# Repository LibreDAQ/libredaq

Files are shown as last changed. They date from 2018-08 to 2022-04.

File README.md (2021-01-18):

# LibreDAQ official repository

LibreDAQ is a versatile, modular and hackable Data Acquisition (DAQ) platform. 
This repository includes the sources for: 
* Circuit schematics
* C++ SDK
* C++ examples
* Firmware
* ROS node
* LibreDAQStudio

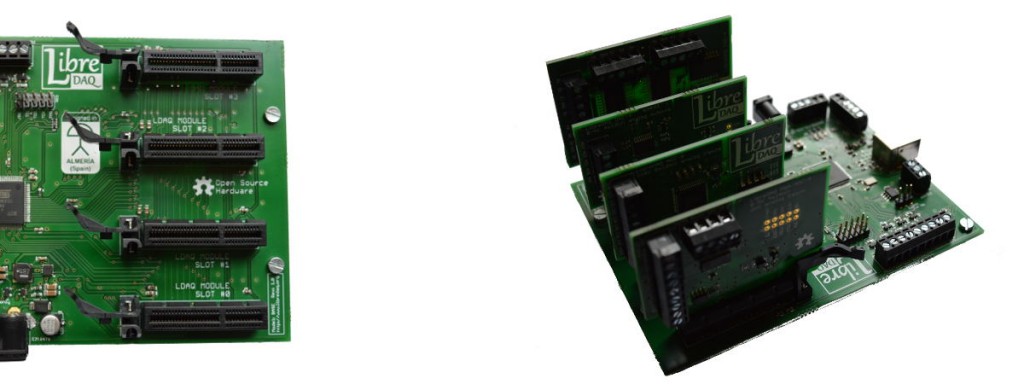
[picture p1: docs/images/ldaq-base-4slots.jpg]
LibreDAQ Picture


# Cite as: 

* Blanco-Claraco, J. L., López-Martínez, J., Torres-Moreno, J. L., & Giménez-Fernández, A. (2015). **A Low-Cost Modular Platform for Heterogeneous Data Acquisition with Accurate Interchannel Synchronization**. *Sensors*, 15(10), 27374-27392 ([PDF](https://www.mdpi.com/1424-8220/15/10/27374/pdf)).
* BibTex:
```
@article{blanco2015low,
  title={A Low-Cost Modular Platform for Heterogeneous Data Acquisition with Accurate Interchannel Synchronization},
  author={Blanco-Claraco, Jos{\'e} Luis and L{\'o}pez-Mart{\'\i}nez, Javier and Torres-Moreno, Jos{\'e} Luis and Gim{\'e}nez-Fern{\'a}ndez, Antonio},
  journal={Sensors},
  volume={15},
  number={10},
  pages={27374--27392},
  year={2015}
}
```

# CircuitHub

* [LibreDAQ Base board](https://circuithub.com/projects/LibreDAQ/ldaq-base-v11)

# Videos:

[YouTube playlist](https://www.youtube.com/playlist?list=PLOJ3GF0x2_eULIKMOQqdDnZAjOUo_N2IJ)

YouTube videos

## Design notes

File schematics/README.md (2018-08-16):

All LibreDAQ schematics are published under the following License:

[Attribution-NonCommercial-ShareAlike 4.0 International](https://creativecommons.org/licenses/by-nc-sa/4.0/)

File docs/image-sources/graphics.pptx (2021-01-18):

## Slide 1

PC

LibreDaq
Base

Module

µController

LibreDaq
Mini

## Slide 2

LDS Interface

Analog & Digital I/Os

…

USB
(480 Mbps)

…

(4 Slots)

USB
(480 Mbps)

Analog & Digital I/Os

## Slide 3

RS/EIA-485 BUS

LDS Interface

Analog & Digital I/Os

…

USB
(480 Mbps)

…

Analog & Digital I/Os

…

LDS Interface

…

Analog & Digital I/Os

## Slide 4

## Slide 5

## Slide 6

P1

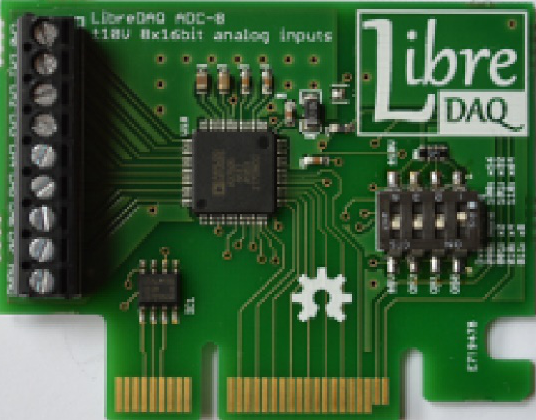
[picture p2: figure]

LDS

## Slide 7

P1

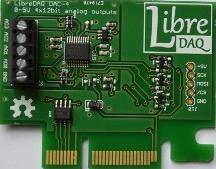
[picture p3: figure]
Screen Clipping

LDS

P2

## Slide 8

P3

P4

P2

P1

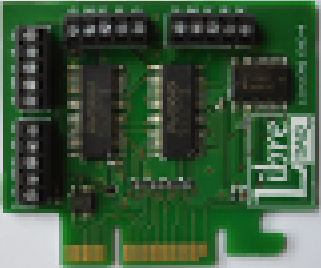
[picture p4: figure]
Screen Clipping

LDS

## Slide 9

P2

P1

P3

LDS

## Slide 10

P2

P3

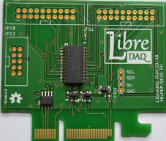
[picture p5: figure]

P1

P4

LDS

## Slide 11

P2

P1

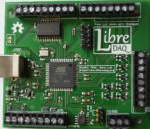
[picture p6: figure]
ldaq-mini-pic1-lowres

USB

P3

P6

P4

P5

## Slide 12

P1

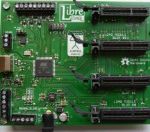
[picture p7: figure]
ldaq-base-pic1-lowres

SLOT3

USB

P2

SLOT2

P3

SLOT1

P5

SLOT0

P4

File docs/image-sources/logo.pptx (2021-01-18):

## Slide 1

L

L

L

ibre

DAQ

VOLTIO1

ibre

DAQ

MINI

ibre

DAQ

PRO

L

L

ibre

DAQ

VOLTIO2

ibre

DAQ

MUEVE

L

ibre

DAQ

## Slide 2

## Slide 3

Designed in

ALMERÍA
(Spain)

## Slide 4

L

DAQ

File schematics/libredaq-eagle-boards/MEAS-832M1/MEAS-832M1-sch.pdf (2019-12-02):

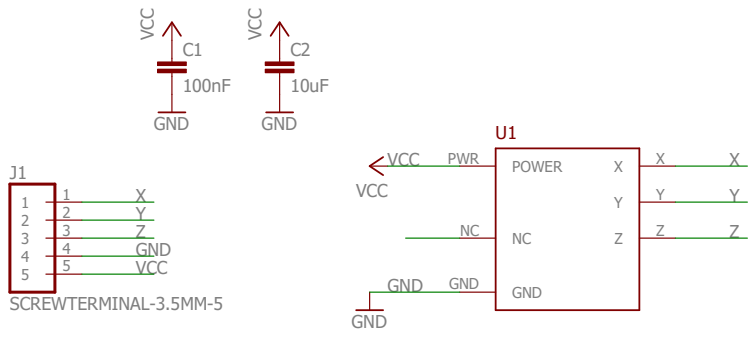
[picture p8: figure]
SCREWTERMINAL-3.5MM-5; GND; VCC VCC; VCC; POWER PWR; GND GND

29/11/2019 17:01 C:\Dropbox\Work\HW\LibreDAQ\libredaq-eagle\MEAS-832M1\MEAS-832M1.sch (Sheet: 1/1)

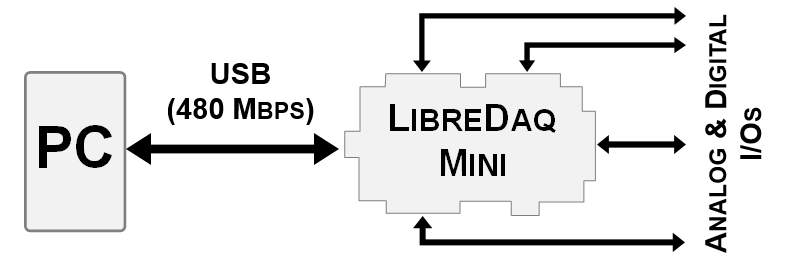
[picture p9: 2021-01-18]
docs/images/ldaq-overview2.png

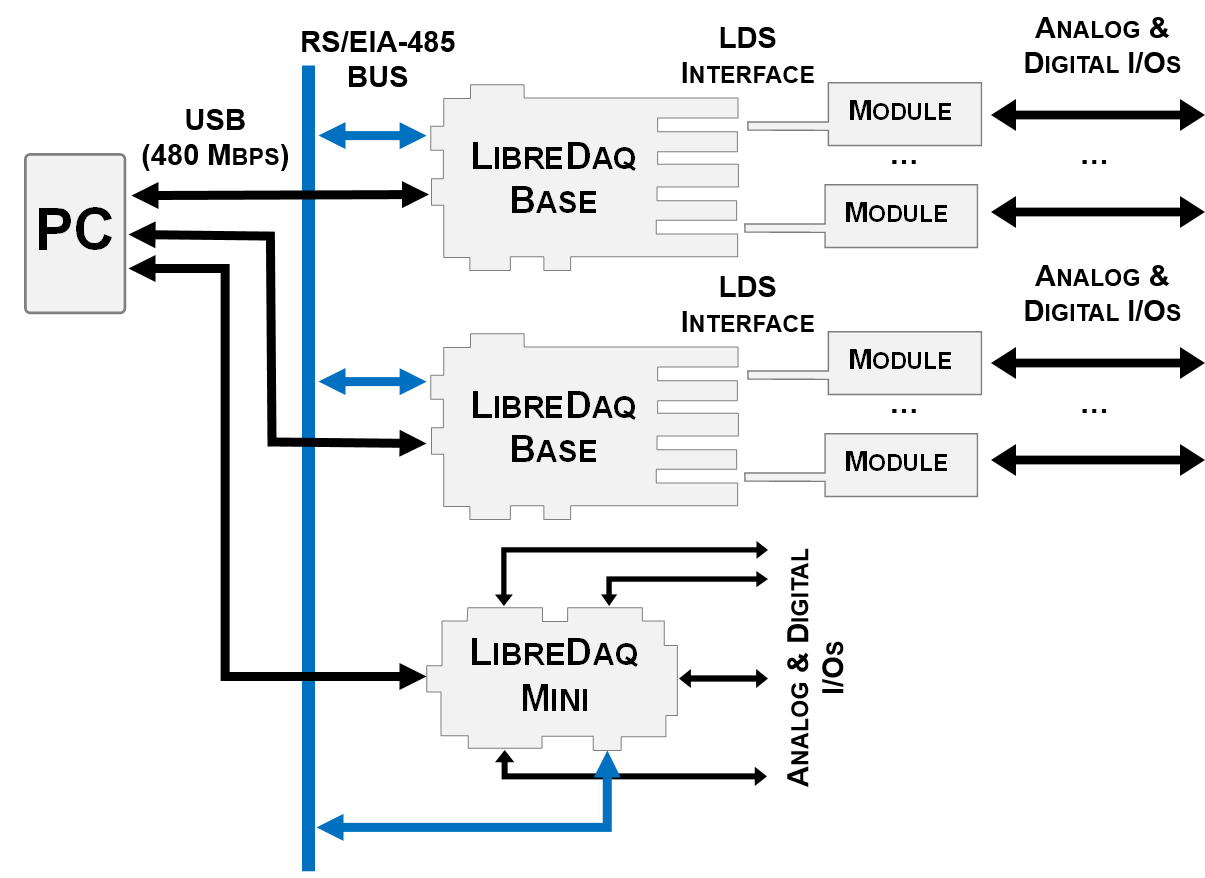
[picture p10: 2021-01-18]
docs/images/ldaq-overview3.png

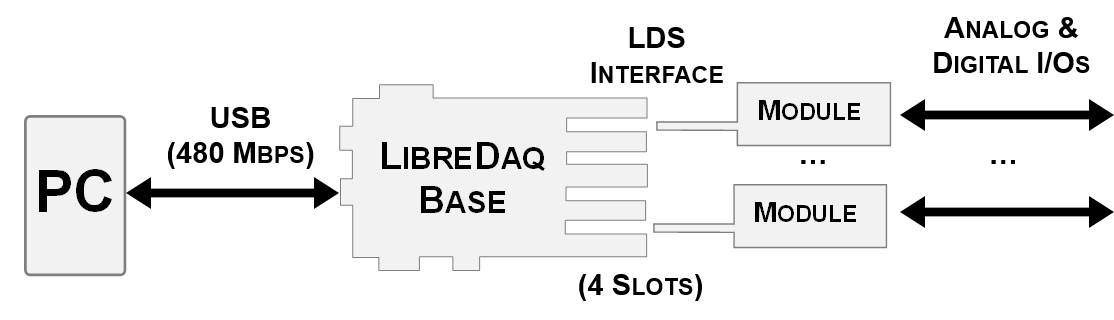
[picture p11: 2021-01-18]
docs/images/ldaq-overview1.png

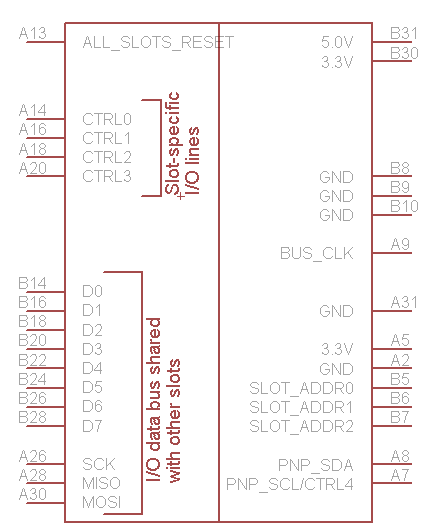
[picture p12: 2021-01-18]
docs/images/LibreDAQ_LDS_Signals.png

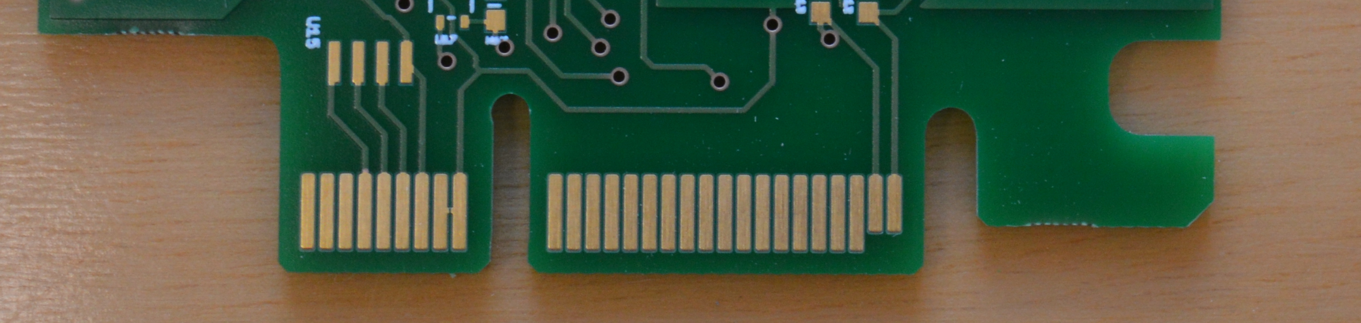
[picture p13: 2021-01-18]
docs/images/LDS-interface-front.jpg

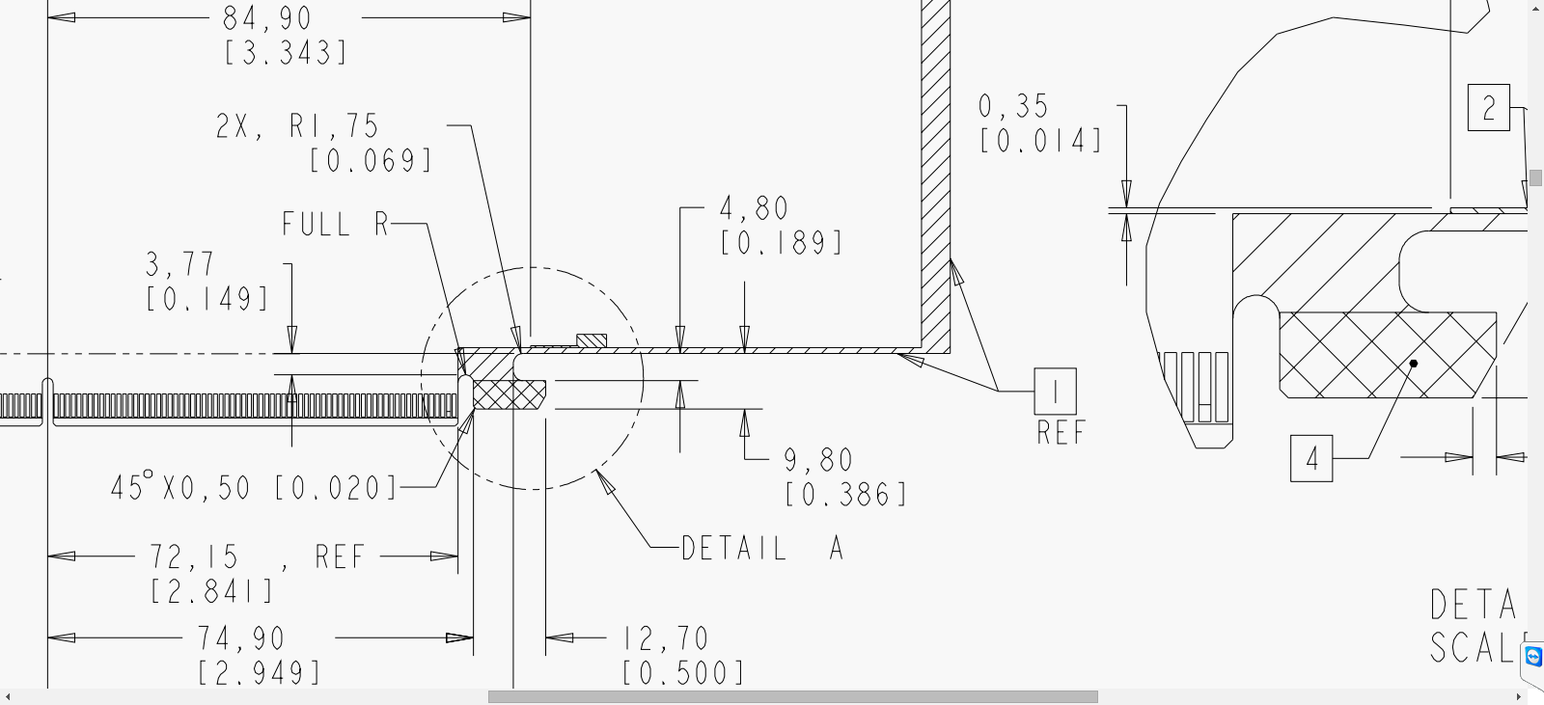
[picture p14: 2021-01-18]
docs/images/pci-express.png

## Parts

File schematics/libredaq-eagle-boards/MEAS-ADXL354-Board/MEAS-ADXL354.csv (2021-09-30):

Qty | Value | Device | Package | Parts | Description | ARROW_PART_NUMBER | ARROW_PRICE-STOCK | DESCRIPTION | HEIGHT | MANUFACTURER_NAME | MANUFACTURER_PART_NUMBER | MOUSER_PART_NUMBER | MOUSER_PRICE-STOCK
4 | 0.1uF | 8,85012E+11 | CAPC1005X55N | C2, C4, C6, C9 | Multilayer Ceramic Chip Capacitor WCAP-CSGP Series 0402 100000pF X5R0402104M010DFCT10000 |  |  | Multilayer Ceramic Chip Capacitor WCAP-CSGP Series 0402 100000pF X5R0402104M010DFCT10000 | 0.55mm | Wurth Elektronik | 8,85012E+11 | 710-885012105010 | https://www.mouser.co.uk/ProductDetail/Wurth-Elektronik/885012105010?qs=0KOYDY2FL298aE%252BL5D%252BNKw%3D%3D
4 | 1.0uF | LMK105BJ225KV-F | CAPC1005X55N | C1, C3, C5, C8 | TAIYO YUDEN - LMK105BJ225KV-F - CAP ,MLCC ,0402,10V ,X5R,2.2UF10% ,T&R |  |  | TAIYO YUDEN - LMK105BJ225KV-F - CAP ,MLCC ,0402,10V ,X5R,2.2UF10% ,T&R | 0.55mm | TAIYO YUDEN | LMK105BJ225KV-F | 963-LMK105BJ225KV-F | https://www.mouser.co.uk/ProductDetail/Taiyo-Yuden/LMK105BJ225KV-F?qs=lkMpTOwszhdMcDOeuc5Dig%3D%3D
1 | 1725698 | 1725698 | 1725698 | J2 | Conn PC Terminal Block 6 POS 2.54mm Solder ST Thru-Hole 6A |  |  | Conn PC Terminal Block 6 POS 2.54mm Solder ST Thru-Hole 6A | 8.65mm | Phoenix Contact | 1725698 | 651-1725698 | https://www.mouser.co.uk/ProductDetail/Phoenix-Contact/1725698?qs=Ul7CXFMnlWUIR3VpVwwC4A%3D%3D
1 | ADXL354CEZ-RL7 | ADXL354CEZ-RL7 | PLCC127P602X560X205-14N | IC1 | Accelerometer Triple +/-2g/+/-8g 3.3V 368mv/g to 432mv/g/92mv/g to 108mv/g 14-Pin CLLCC T/R |  |  | Accelerometer Triple +/-2g/+/-8g 3.3V 368mv/g to 432mv/g/92mv/g to 108mv/g 14-Pin CLLCC T/R | 2.05mm | Analog Devices | ADXL354CEZ-RL7 |  | https://www.digikey.com/es/products/detail/analog-devices-inc/ADXL354CEZ-RL7/6618309
1 | SFR03EZPF6801 | SFR03EZPF6801 | RESC1608X55N | R6 | Thick Film Resistors - SMD 0603 6.8Kohms 1% Anti-Sulfur AEC-Q200 |  |  | Thick Film Resistors - SMD 0603 6.8Kohms 1% Anti-Sulfur AEC-Q200 | 0.55mm | ROHM Semiconductor | SFR03EZPF6801 |  | https://eu.mouser.com/ProductDetail/ROHM-Semiconductor/SFR03EZPF6801?qs=byeeYqUIh0P3tMvw9zV%2F5Q%3D%3D

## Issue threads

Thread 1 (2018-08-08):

Where is circuit schematics located?

lauritk, 2018-08-08:
Hi, I could not find the circuit schematics?

jlblancoc, 2018-08-10:
I will look for them and upload to this Repository!

lauritk, 2018-08-16:
Thank you! I will contribute improvements, if any :)

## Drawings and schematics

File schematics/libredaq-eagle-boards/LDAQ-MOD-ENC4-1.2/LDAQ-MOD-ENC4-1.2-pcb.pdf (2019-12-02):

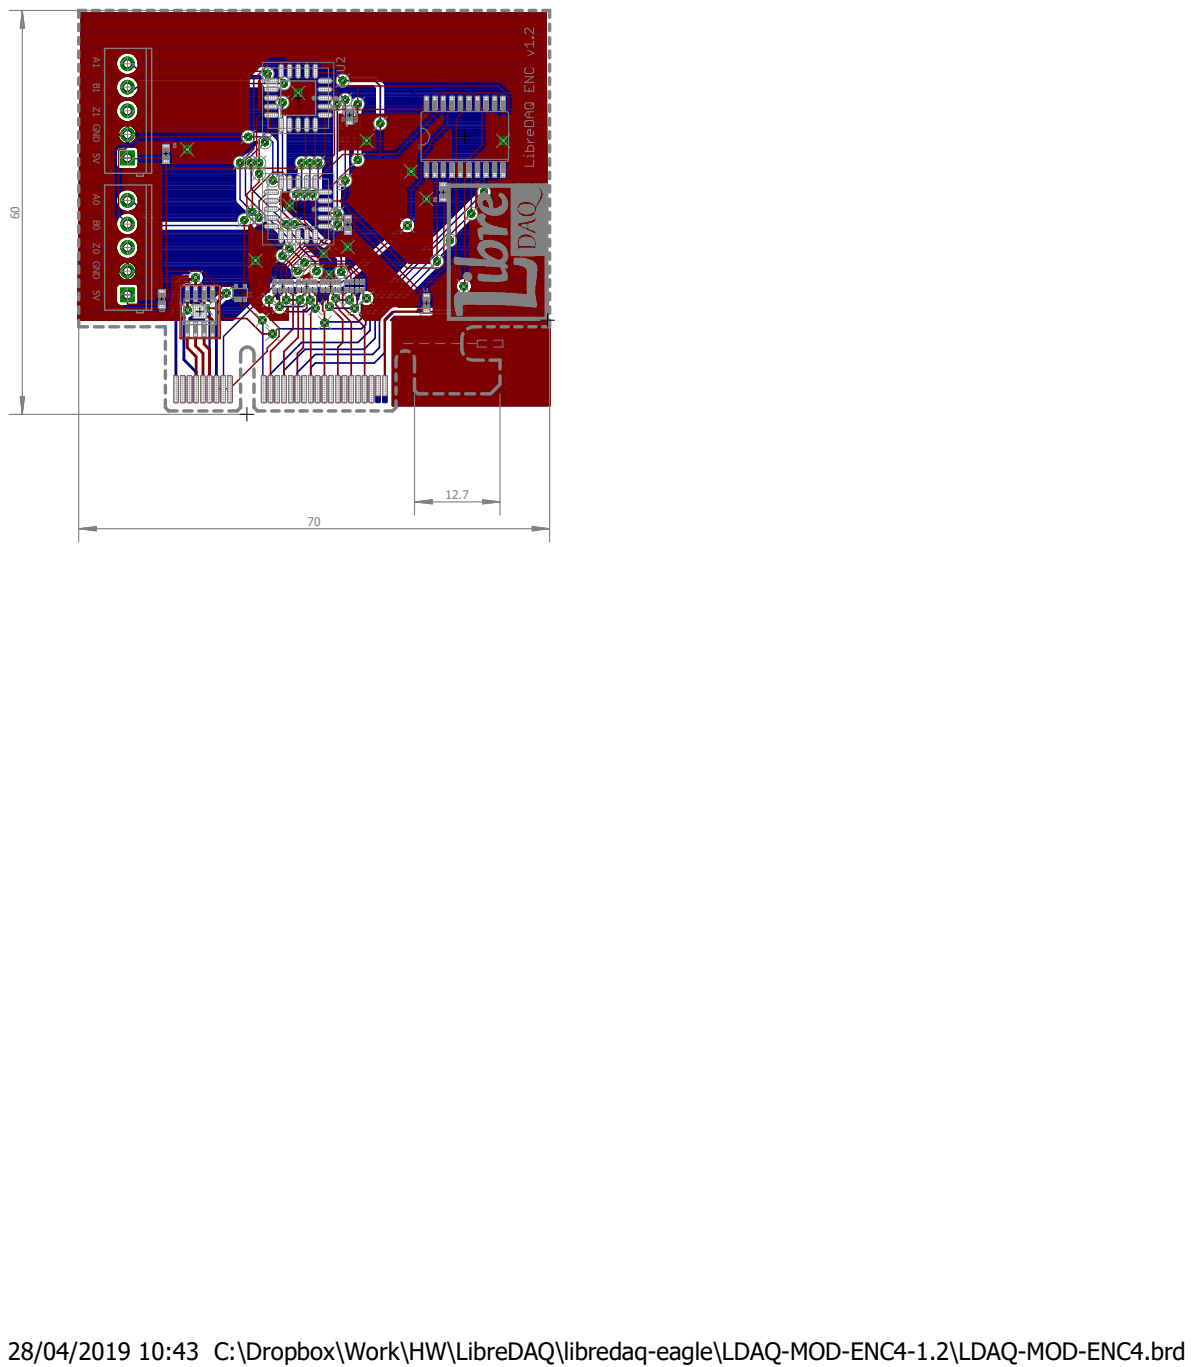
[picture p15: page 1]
GND 5V Z1 B1 A1 GND 5V Z0 B0 A0

28/04/2019 10:43 C:\Dropbox\Work\HW\LibreDAQ\libredaq-eagle\LDAQ-MOD-ENC4-1.2\LDAQ-MOD-ENC4.brd

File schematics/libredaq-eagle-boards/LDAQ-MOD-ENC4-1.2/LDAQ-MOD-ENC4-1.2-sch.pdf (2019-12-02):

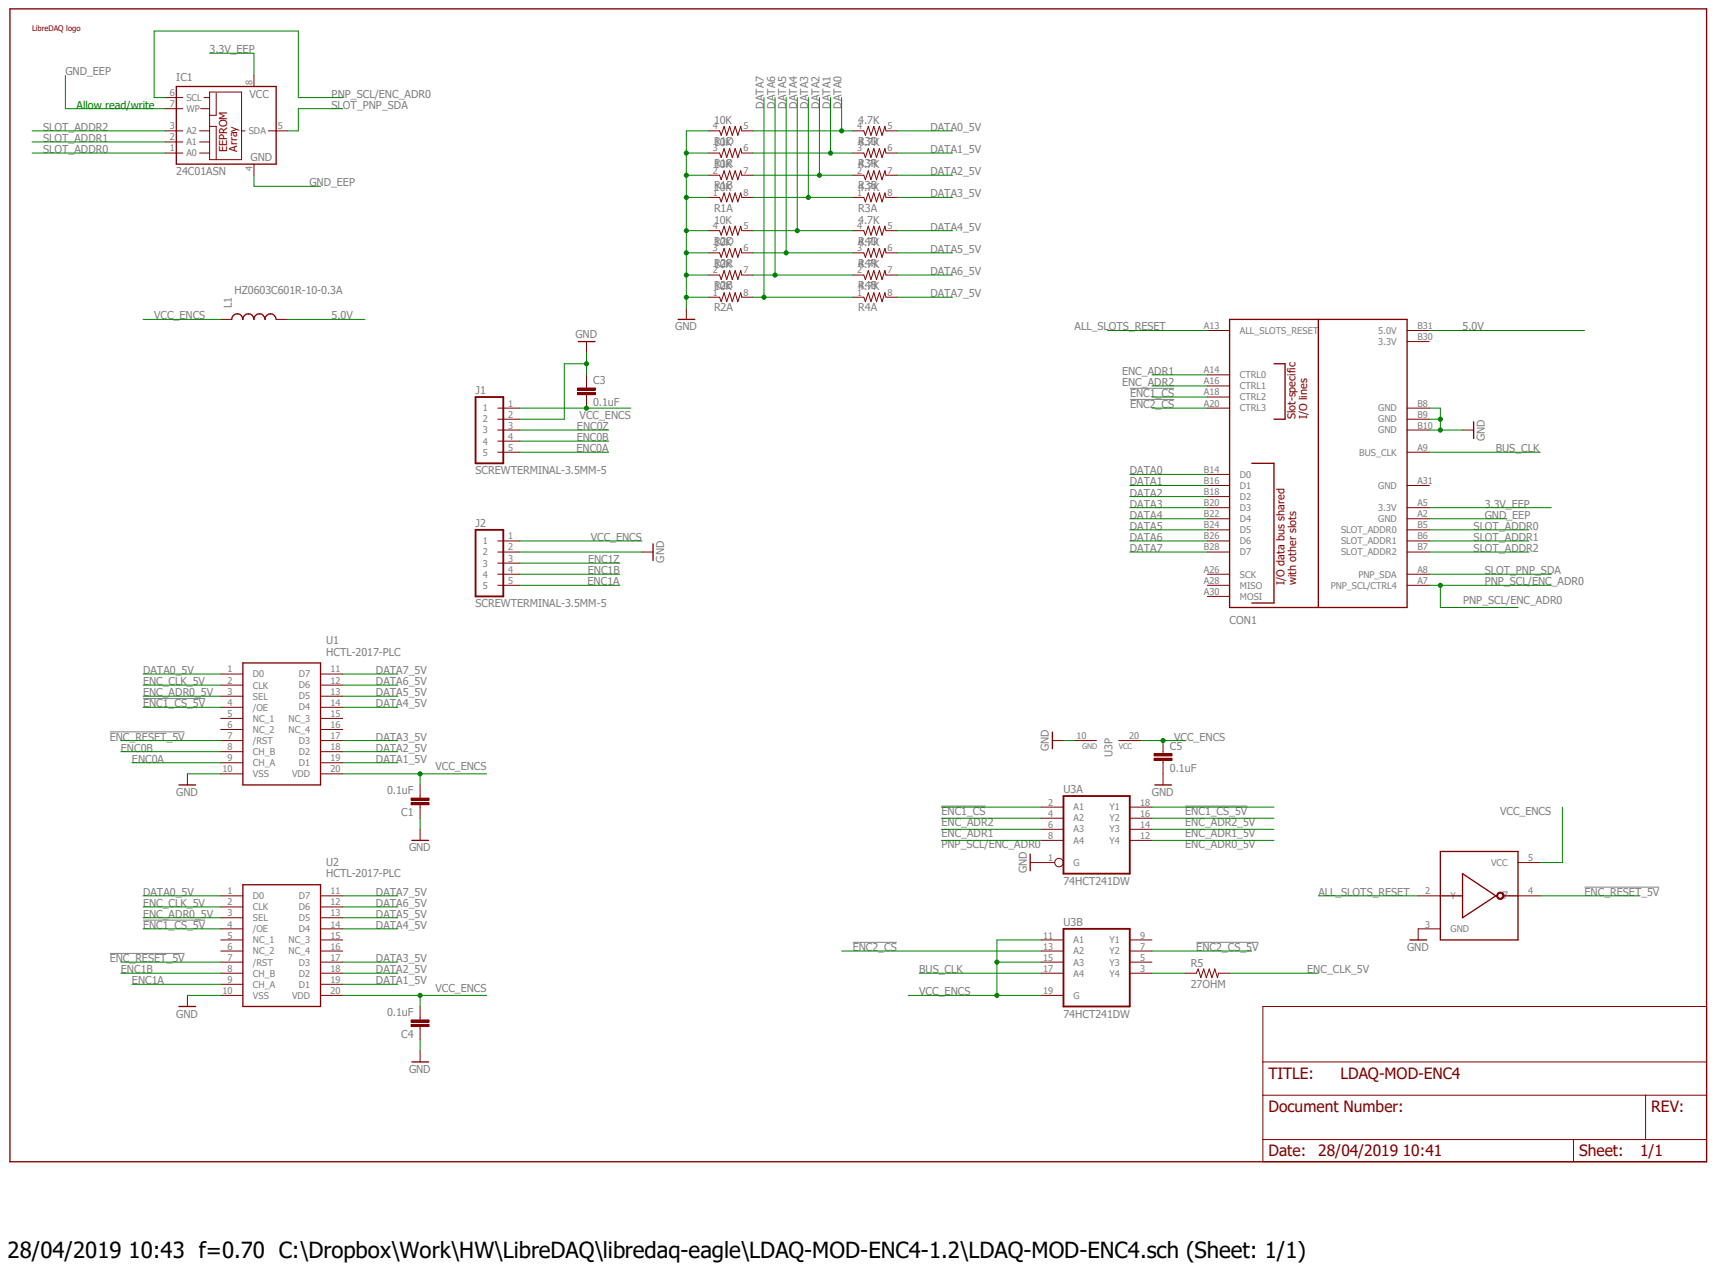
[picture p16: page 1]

DATA0 DATA⁰
LDAQ-MOD-ENC4 I/O data bus shared with other slots Slot-specific I/O lines

Document Number: | REV:

Date: 28/04/2019 10:41 | Sheet: 1/1

28/04/2019 10:43 f=0.70 C:\Dropbox\Work\HW\LibreDAQ\libredaq-eagle\LDAQ-MOD-ENC4-1.2\LDAQ-MOD-ENC4.sch (Sheet: 1/1)

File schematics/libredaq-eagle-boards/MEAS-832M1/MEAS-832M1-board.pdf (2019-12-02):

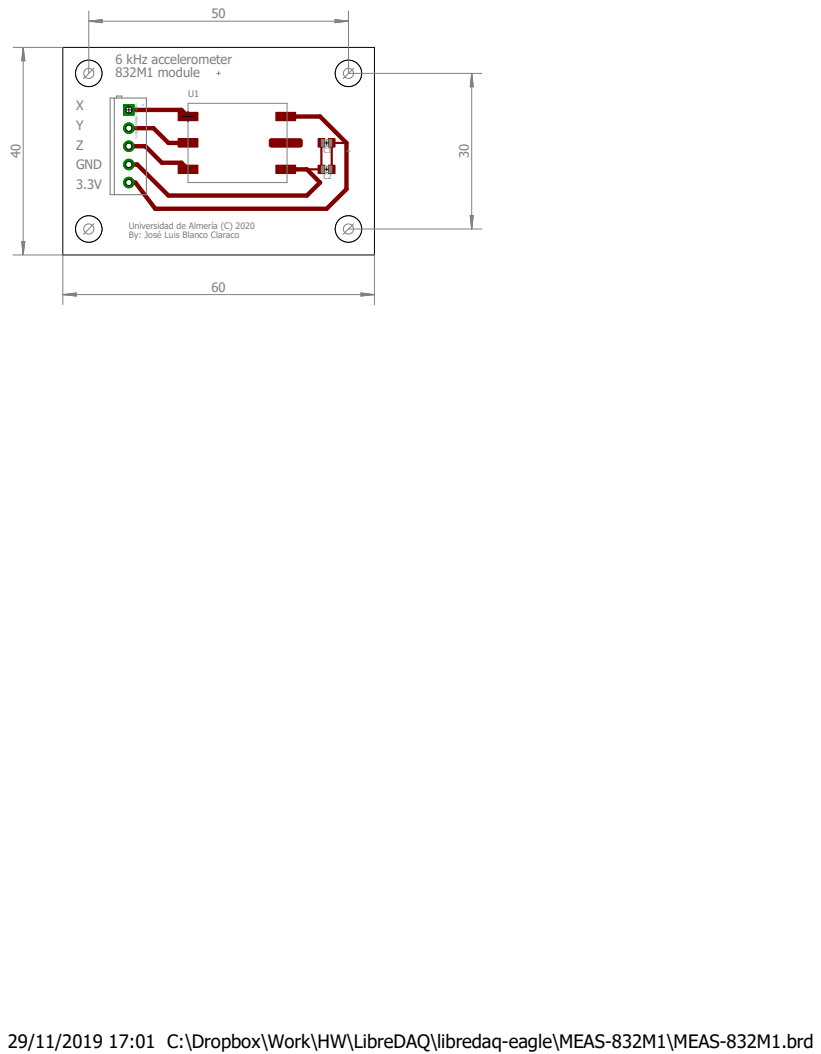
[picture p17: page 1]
6 kHz accelerometer; X Y Z GND 3.3V; 832M1 module; C2 SCREWTERMINAL⁻3.5MM⁻⁵ 40

Universidad de Almería (C) 2020
By: José Luis Blanco Claraco

29/11/2019 17:01 C:\Dropbox\Work\HW\LibreDAQ\libredaq-eagle\MEAS-832M1\MEAS-832M1.brd

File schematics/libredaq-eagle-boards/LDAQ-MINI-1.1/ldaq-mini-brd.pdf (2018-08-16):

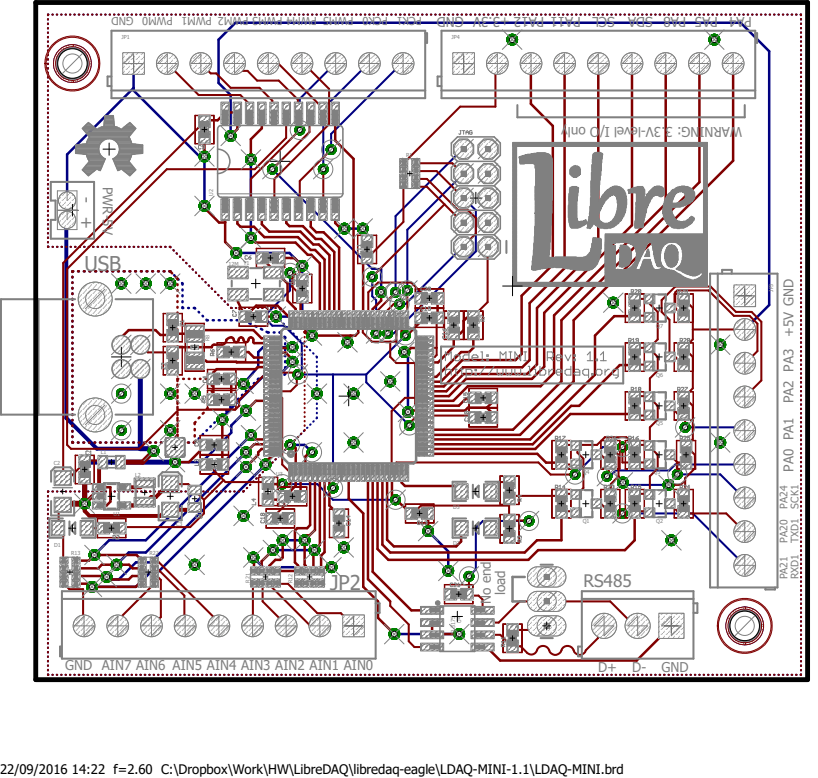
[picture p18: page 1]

22/09/2016 14:22 f=2.60 C:\Dropbox\Work\HW\LibreDAQ\libredaq-eagle\LDAQ-MINI-1.1\LDAQ-MINI.brd ⁺ ⁻
USB

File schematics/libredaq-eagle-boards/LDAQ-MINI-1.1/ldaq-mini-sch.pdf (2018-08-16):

# PA5_3.3 USB

A

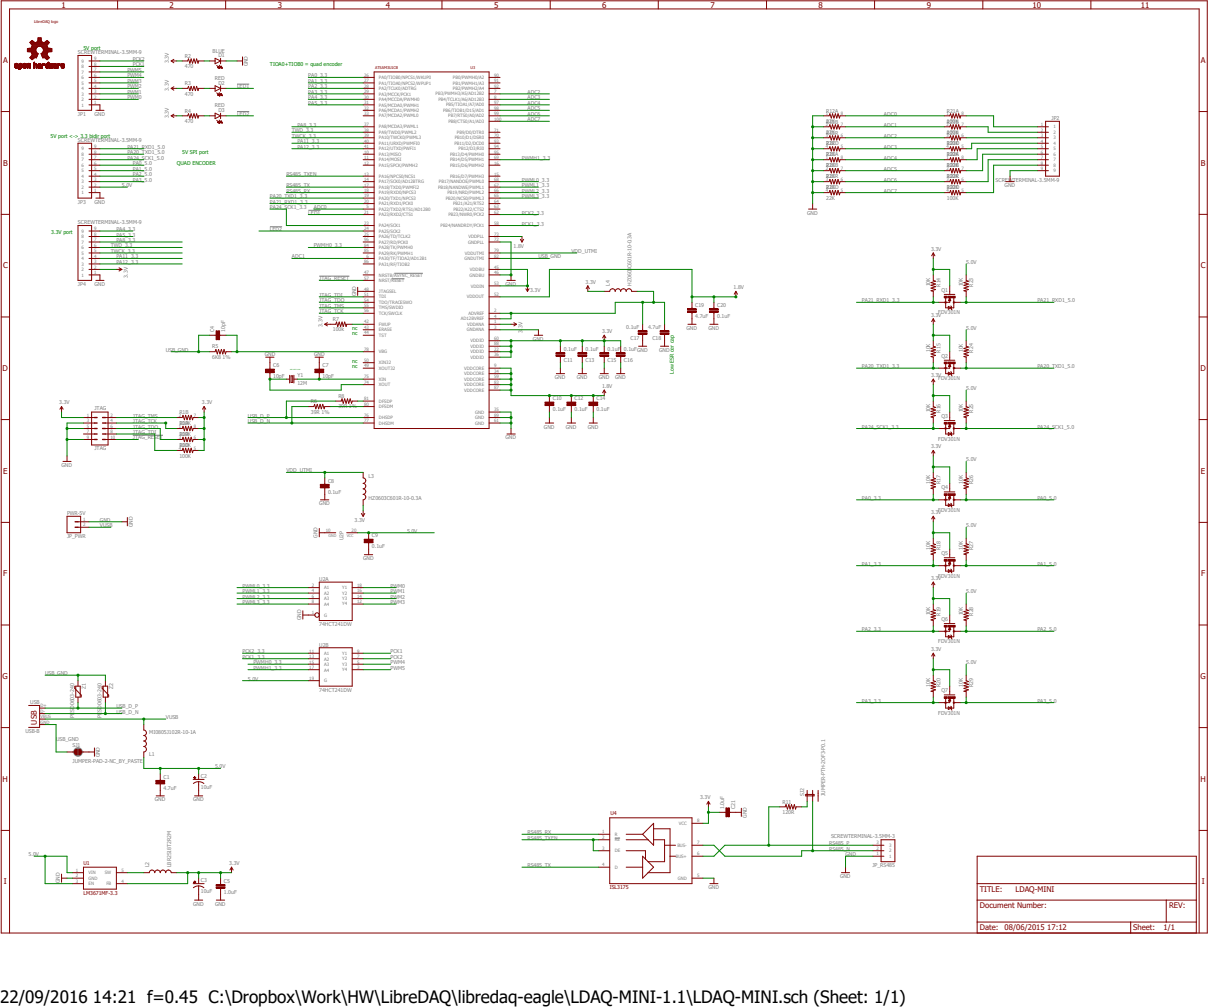
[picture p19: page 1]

22/09/2016 14:21 f=0.45 C:\Dropbox\Work\HW\LibreDAQ\libredaq-eagle\LDAQ-MINI-1.1\LDAQ-MINI.sch (Sheet: 1/1)

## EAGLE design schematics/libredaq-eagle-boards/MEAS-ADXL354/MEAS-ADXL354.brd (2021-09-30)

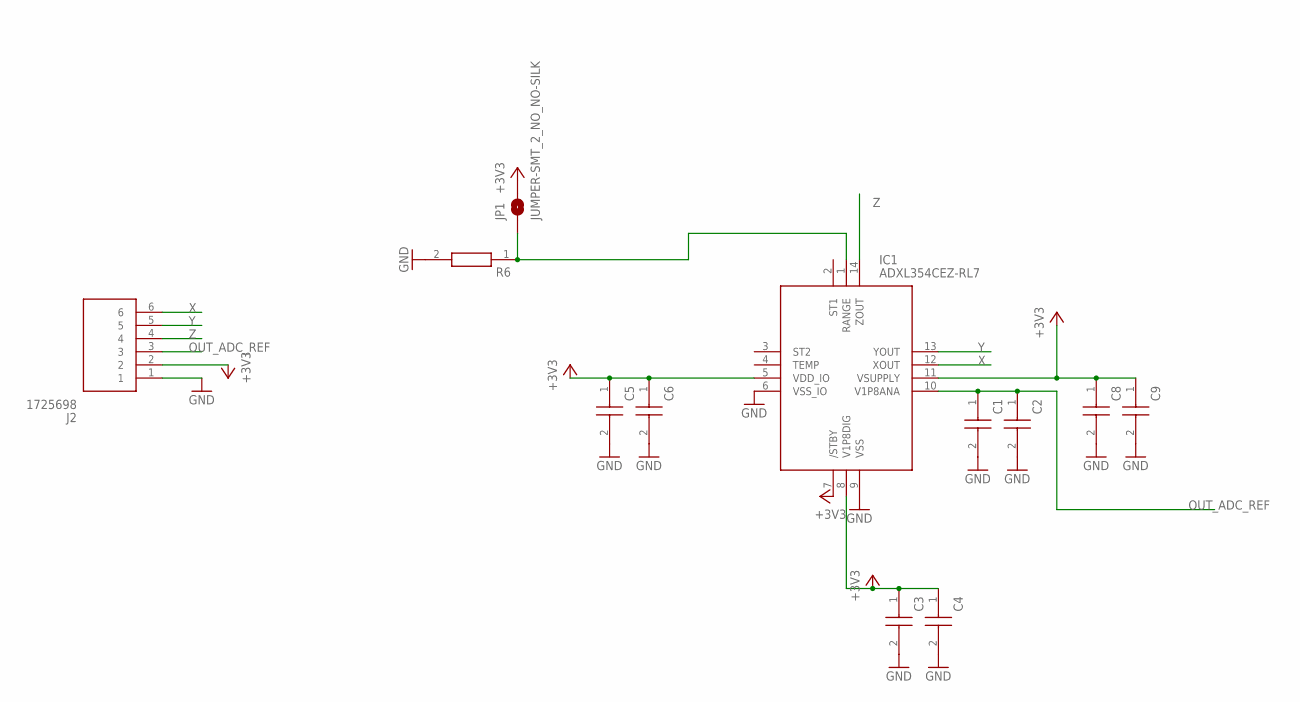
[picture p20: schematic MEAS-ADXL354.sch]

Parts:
C1, C3, C5, C8: 1.0uF; CAPC1005X55N
C2, C4, C6, C9: 0.1uF; CAPC1005X55N
IC1: ADXL354CEZ-RL7; PLCC127P602X560X205-14N
J2: 1725698
JP1: JUMPER-SMT_2_NO_NO-SILK; SMT-JUMPER_2_NO_NO-SILK
R6: SFR03EZPF6801; RESC1608X55N

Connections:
+3V3: C3.1, C4.1, C5.1, C6.1, C8.1, C9.1, IC1.5 (VDD_IO), IC1.7 (/STBY), IC1.8 (V1P8DIG), IC1.11 (VSUPPLY), J2.2, JP1.2
GND: C1.2, C2.2, C3.2, C4.2, C5.2, C6.2, C8.2, C9.2, IC1.6 (VSS_IO), IC1.9 (VSS), J2.1, R6.2
unnamed: IC1.1 (RANGE), JP1.1, R6.1
OUT_ADC_REF: C1.1, C2.1, IC1.10 (V1P8ANA), J2.3
X: IC1.12 (XOUT), J2.6
Y: IC1.13 (YOUT), J2.5
Z: IC1.14 (ZOUT), J2.4

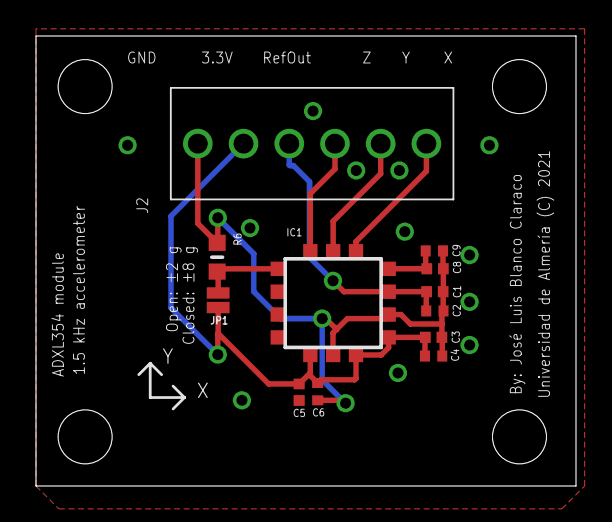
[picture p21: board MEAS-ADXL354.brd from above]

Board: 2 copper layers, 30.0 x 25.0 mm, 12 parts (0 on the bottom side), 7 nets.

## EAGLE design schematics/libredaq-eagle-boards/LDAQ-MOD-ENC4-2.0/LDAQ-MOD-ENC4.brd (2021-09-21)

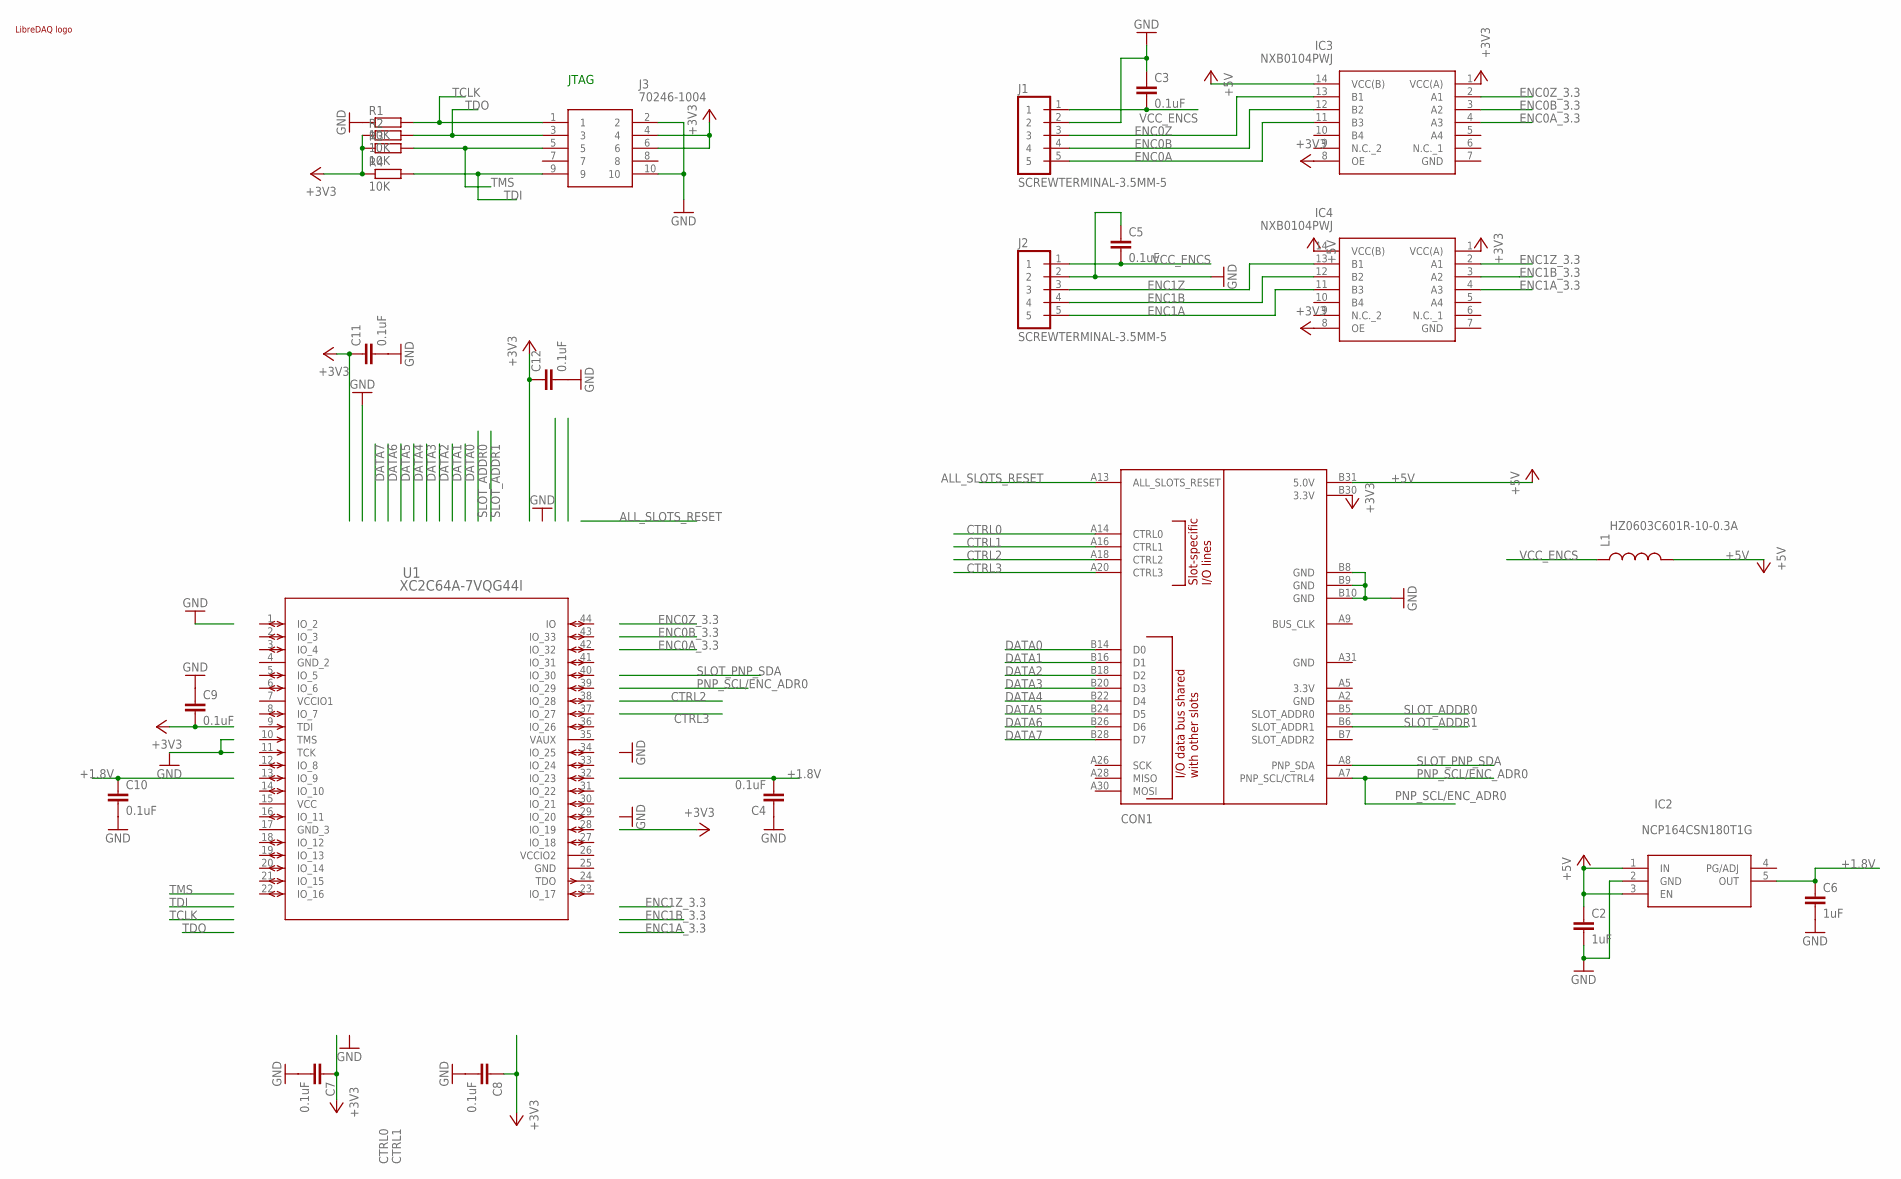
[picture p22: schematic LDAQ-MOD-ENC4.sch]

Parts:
C2, C6: 1uF; C0603
C3, C4, C5, C7, C8, C9, C10, C11, C12: 0.1uF; 0603-CAP
CON1: BOARD; PCI-E_64_EDGE_70X60_PADS-ONLY
IC2: NCP164CSN180T1G; SOT95P275X110-5N
IC3, IC4: NXB0104PWJ; SOP65P640X110-14N
J1, J2: SCREWTERMINAL-3.5MM-5
J3: 70246-1004; SHDR10W64P254_2X5_2032X889X927
L1: HZ0603C601R-10-0.3A; 0603
LOGO1: LIBREDAQ_LOGO_MINILOGO_GENERIC; LIBREDAQ_LOGO
R1, R2, R3, R4: 10K; R0603
U1: XC2C64A-7VQG44I; 44-VQFP_XIL

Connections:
+1.8V: C4.2, C6.1, C10.1, IC2.5 (OUT)
+3V3: C7.1, C8.1, C9.2, C11.1, C12.1, CON1.B30 (3.3V), IC3.1 (VCC(A)), IC3.8 (OE), IC4.1 (VCC(A)), IC4.8 (OE), J3.4, J3.6, R2.1, R3.1, R4.1
+5V: C2.1, CON1.B31 (5.0V), IC2.1 (IN), IC2.3 (EN), IC3.14 (VCC(B)), IC4.14 (VCC(B)), L1.2
ALL_SLOTS_RESET: CON1.A13 (ALL_SLOTS_RESET)
CTRL0: CON1.A14 (CTRL0)
CTRL1: CON1.A16 (CTRL1)
CTRL2: CON1.A18 (CTRL2)
CTRL3: CON1.A20 (CTRL3)
DATA0: CON1.B14 (D0)
DATA1: CON1.B16 (D1)
DATA2: CON1.B18 (D2)
DATA3: CON1.B20 (D3)
DATA4: CON1.B22 (D4)
DATA5: CON1.B24 (D5)
DATA6: CON1.B26 (D6)
DATA7: CON1.B28 (D7)
ENC0A: IC3.11 (B3), J1.5
ENC0A_3.3: IC3.4 (A3)
ENC0B: IC3.12 (B2), J1.4
ENC0B_3.3: IC3.3 (A2)
ENC0Z: IC3.13 (B1), J1.3
ENC0Z_3.3: IC3.2 (A1)
ENC1A: IC4.11 (B3), J2.5
ENC1A_3.3: IC4.4 (A3)
ENC1B: IC4.12 (B2), J2.4
ENC1B_3.3: IC4.3 (A2)
ENC1Z: IC4.13 (B1), J2.3
ENC1Z_3.3: IC4.2 (A1)
GND: C2.2, C3.1, C4.1, C5.1, C6.2, C7.2, C8.2, C9.1, C10.2, C11.2, C12.2, CON1.B8 (GND), CON1.B9 (GND), CON1.B10 (GND), IC2.2 (GND), J1.2, J2.2, J3.2, J3.10, R1.1, U1.25 (GND)
GND_2: U1.4 (GND_2)
GND_3: U1.17 (GND_3)
PNP_SCL/ENC_ADR0: CON1.A7 (PNP_SCL/CTRL4)
SLOT_ADDR0: CON1.B5 (SLOT_ADDR0)
SLOT_ADDR1: CON1.B6 (SLOT_ADDR1)
SLOT_PNP_SDA: CON1.A8 (PNP_SDA)
TCLK: J3.1, R1.2
TDI: J3.9, R4.2
TDO: J3.3, R2.2
TMS: J3.5, R3.2
VAUX: U1.35 (VAUX)
VCC: U1.15 (VCC)
VCCIO1: U1.7 (VCCIO1)
VCCIO2: U1.26 (VCCIO2)
VCC_ENCS: C3.2, C5.2, J1.1, J2.1, L1.1

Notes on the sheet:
JTAG

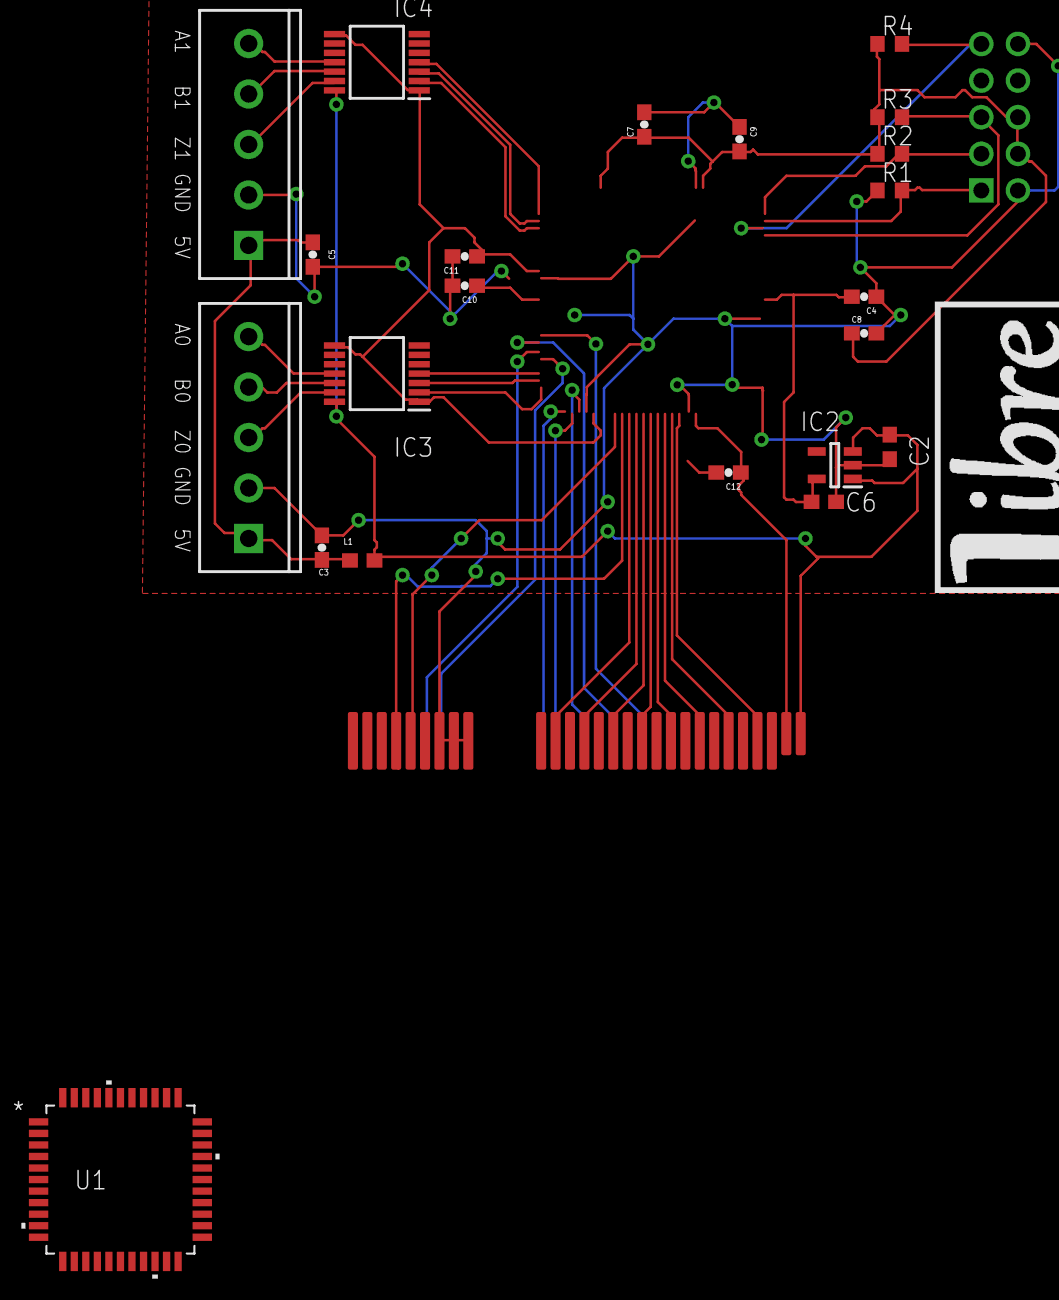
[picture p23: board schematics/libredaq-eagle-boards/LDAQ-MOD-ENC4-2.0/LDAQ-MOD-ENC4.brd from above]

Board: 2 copper layers, 25 parts (1 on the bottom side), 15 nets.

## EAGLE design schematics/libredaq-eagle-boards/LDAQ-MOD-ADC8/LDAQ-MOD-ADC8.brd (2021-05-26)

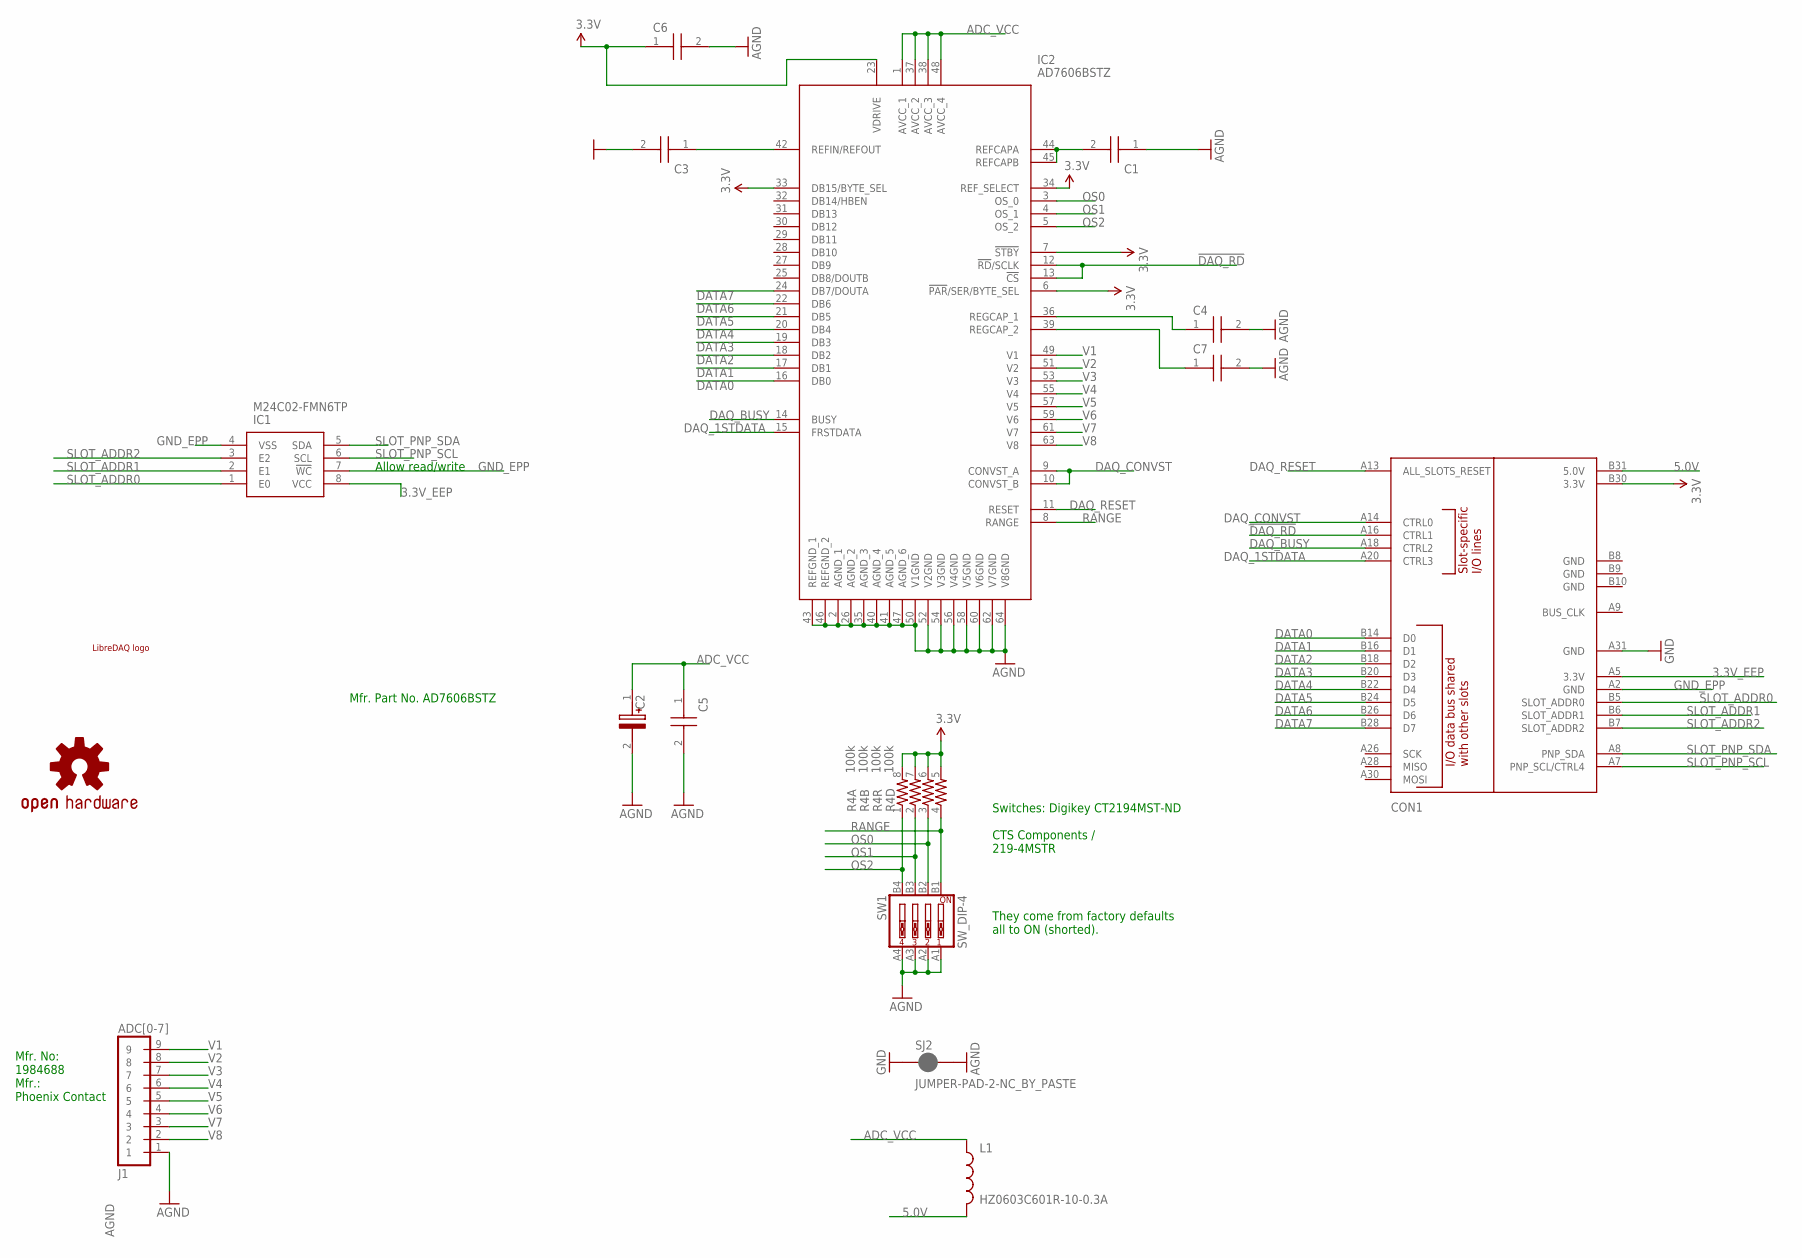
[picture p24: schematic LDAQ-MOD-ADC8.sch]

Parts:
C1, C3: 10uF; CAPC1005X55N
C2: 10uF; CAPPM3528X210N
C4, C7: 1.0uF; CAPC1005X55N
C5, C6: 0.1uF; CAPC1005X55N
CON1: BOARD; PCI-E_64_EDGE_63X50
IC1: M24C02-FMN6TP; SOIC127P600X175-8N
IC2: AD7606BSTZ; QFP50P1200X1200X160-64N
J1: ADC[0-7]; SCREWTERMINAL-3.5MM-9
L1: HZ0603C601R-10-0.3A; 0603
LOGO1: LIBREDAQ_LOGO_MINILOGO_GENERIC; LIBREDAQ_LOGO
LOGO2: OSHW-LOGOL; OSHW-LOGO-L
R4: 100k; 0603-ARV
SJ2: JUMPER-PAD-2-NC_BY_PASTE; PAD-JUMPER-2-NC_BY_PASTE_YES_SILK
SW1: SW_DIP-4; SW_SIP-4

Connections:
3.3V: C6.1, CON1.B30 (3.3V), IC2.6 (!PAR!/SER/BYTE_SEL), IC2.7 (!STBY), IC2.23 (VDRIVE), IC2.33 (DB15/BYTE_SEL), IC2.34 (REF_SELECT), R4.5 (2), R4.6 (2), R4.7 (2), R4.8 (2)
3.3V_EEP: CON1.A5 (3.3V), IC1.8 (VCC)
5.0V: CON1.B31 (5.0V), L1.2
!DAQ_RD: CON1.A16 (CTRL1), IC2.12 (!RD!/SCLK), IC2.13 (!CS)
ADC_VCC: C2.1 (+), C5.1, IC2.1 (AVCC_1), IC2.37 (AVCC_2), IC2.38 (AVCC_3), IC2.48 (AVCC_4), L1.1
AGND: C1.1, C2.2 (-), C3.2, C4.2, C5.2, C6.2, C7.2, IC2.2 (AGND_1), IC2.26 (AGND_2), IC2.35 (AGND_3), IC2.40 (AGND_4), IC2.41 (AGND_5), IC2.43 (REFGND_1), IC2.46 (REFGND_2), IC2.47 (AGND_6), IC2.50 (V1GND), IC2.52 (V2GND), IC2.54 (V3GND), IC2.56 (V4GND), IC2.58 (V5GND), IC2.60 (V6GND), IC2.62 (V7GND), IC2.64 (V8GND), J1.1, SJ2.2, SW1.A1, SW1.A2, SW1.A3, SW1.A4
DAQ_1STDATA: CON1.A20 (CTRL3), IC2.15 (FRSTDATA)
DAQ_BUSY: CON1.A18 (CTRL2), IC2.14 (BUSY)
DAQ_CONVST: CON1.A14 (CTRL0), IC2.9 (CONVST_A), IC2.10 (CONVST_B)
DAQ_RESET: CON1.A13 (ALL_SLOTS_RESET), IC2.11 (RESET)
DATA0: CON1.B14 (D0), IC2.16 (DB0)
DATA1: CON1.B16 (D1), IC2.17 (DB1)
DATA2: CON1.B18 (D2), IC2.18 (DB2)
DATA3: CON1.B20 (D3), IC2.19 (DB3)
DATA4: CON1.B22 (D4), IC2.20 (DB4)
DATA5: CON1.B24 (D5), IC2.21 (DB5)
DATA6: CON1.B26 (D6), IC2.22 (DB6)
DATA7: CON1.B28 (D7), IC2.24 (DB7/DOUTA)
GND: CON1.A31 (GND), SJ2.1
GND_EPP: CON1.A2 (GND), IC1.4 (VSS), IC1.7 (!WC)
unnamed: C1.2, IC2.44 (REFCAPA), IC2.45 (REFCAPB)
unnamed: C4.1, IC2.36 (REGCAP_1)
unnamed: C7.1, IC2.39 (REGCAP_2)
unnamed: C3.1, IC2.42 (REFIN/REFOUT)
OS0: IC2.3 (OS_0), R4.3 (1), SW1.B2
OS1: IC2.4 (OS_1), R4.2 (1), SW1.B3
OS2: IC2.5 (OS_2), R4.1, SW1.B4
RANGE: IC2.8 (RANGE), R4.4 (1), SW1.B1
SLOT_ADDR0: CON1.B5 (SLOT_ADDR0), IC1.1 (E0)
SLOT_ADDR1: CON1.B6 (SLOT_ADDR1), IC1.2 (E1)
SLOT_ADDR2: CON1.B7 (SLOT_ADDR2), IC1.3 (E2)
SLOT_PNP_SCL: CON1.A7 (PNP_SCL/CTRL4), IC1.6 (SCL)
SLOT_PNP_SDA: CON1.A8 (PNP_SDA), IC1.5 (SDA)
V1: IC2.49 (V1), J1.9
V2: IC2.51 (V2), J1.8
V3: IC2.53 (V3), J1.7
V4: IC2.55 (V4), J1.6
V5: IC2.57 (V5), J1.5
V6: IC2.59 (V6), J1.4
V7: IC2.61 (V7), J1.3
V8: IC2.63 (V8), J1.2

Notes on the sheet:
Allow read/write
Switches: Digikey CT2194MST-ND CTS Components / 219-4MSTR They come from factory defaults all to ON (shorted).
Mfr. No: 1984688 Mfr.: Phoenix Contact
Mfr. Part No. AD7606BSTZ

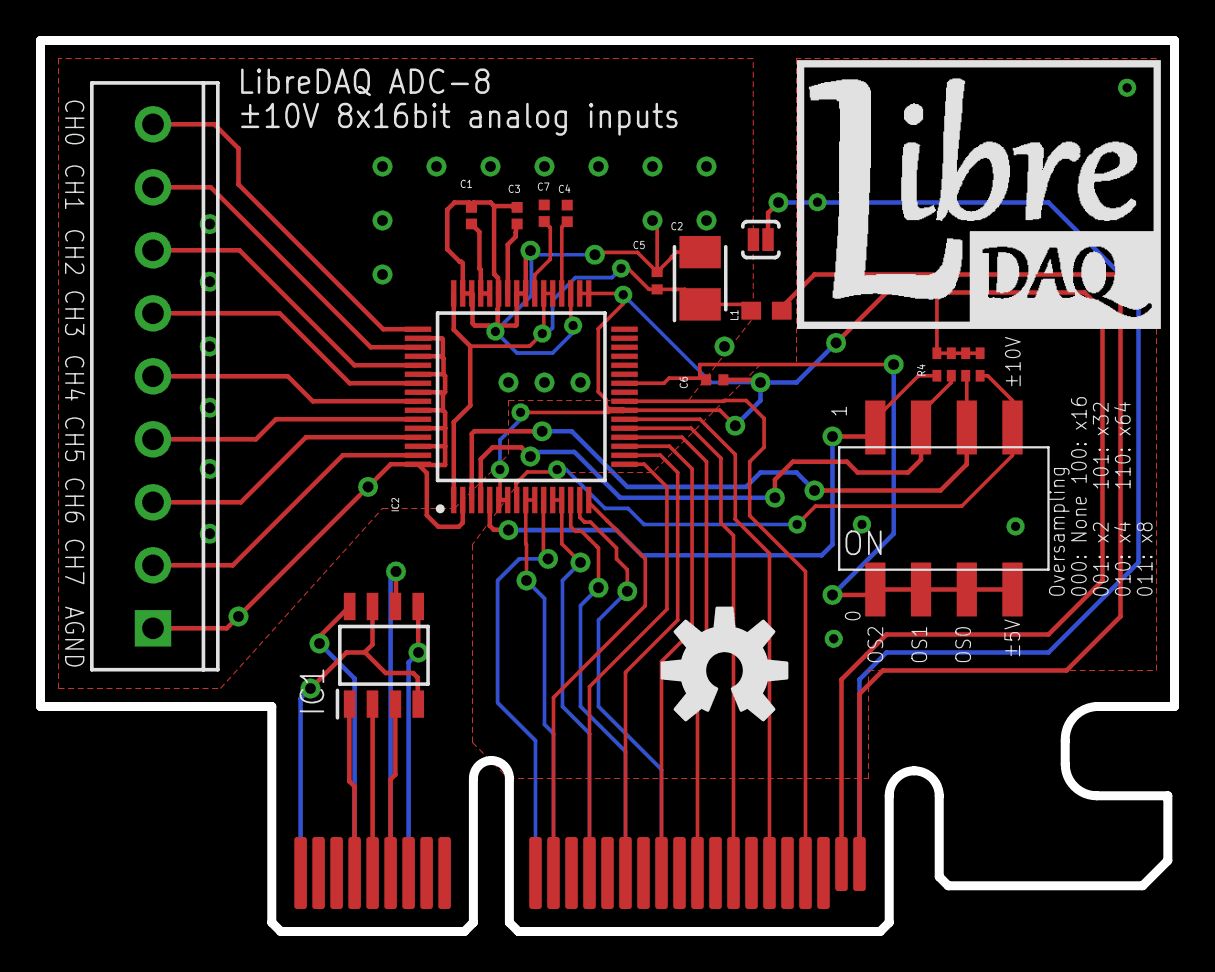
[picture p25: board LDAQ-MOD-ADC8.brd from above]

Board: 2 copper layers, 63.0 x 49.5 mm, 17 parts (0 on the bottom side), 41 nets.

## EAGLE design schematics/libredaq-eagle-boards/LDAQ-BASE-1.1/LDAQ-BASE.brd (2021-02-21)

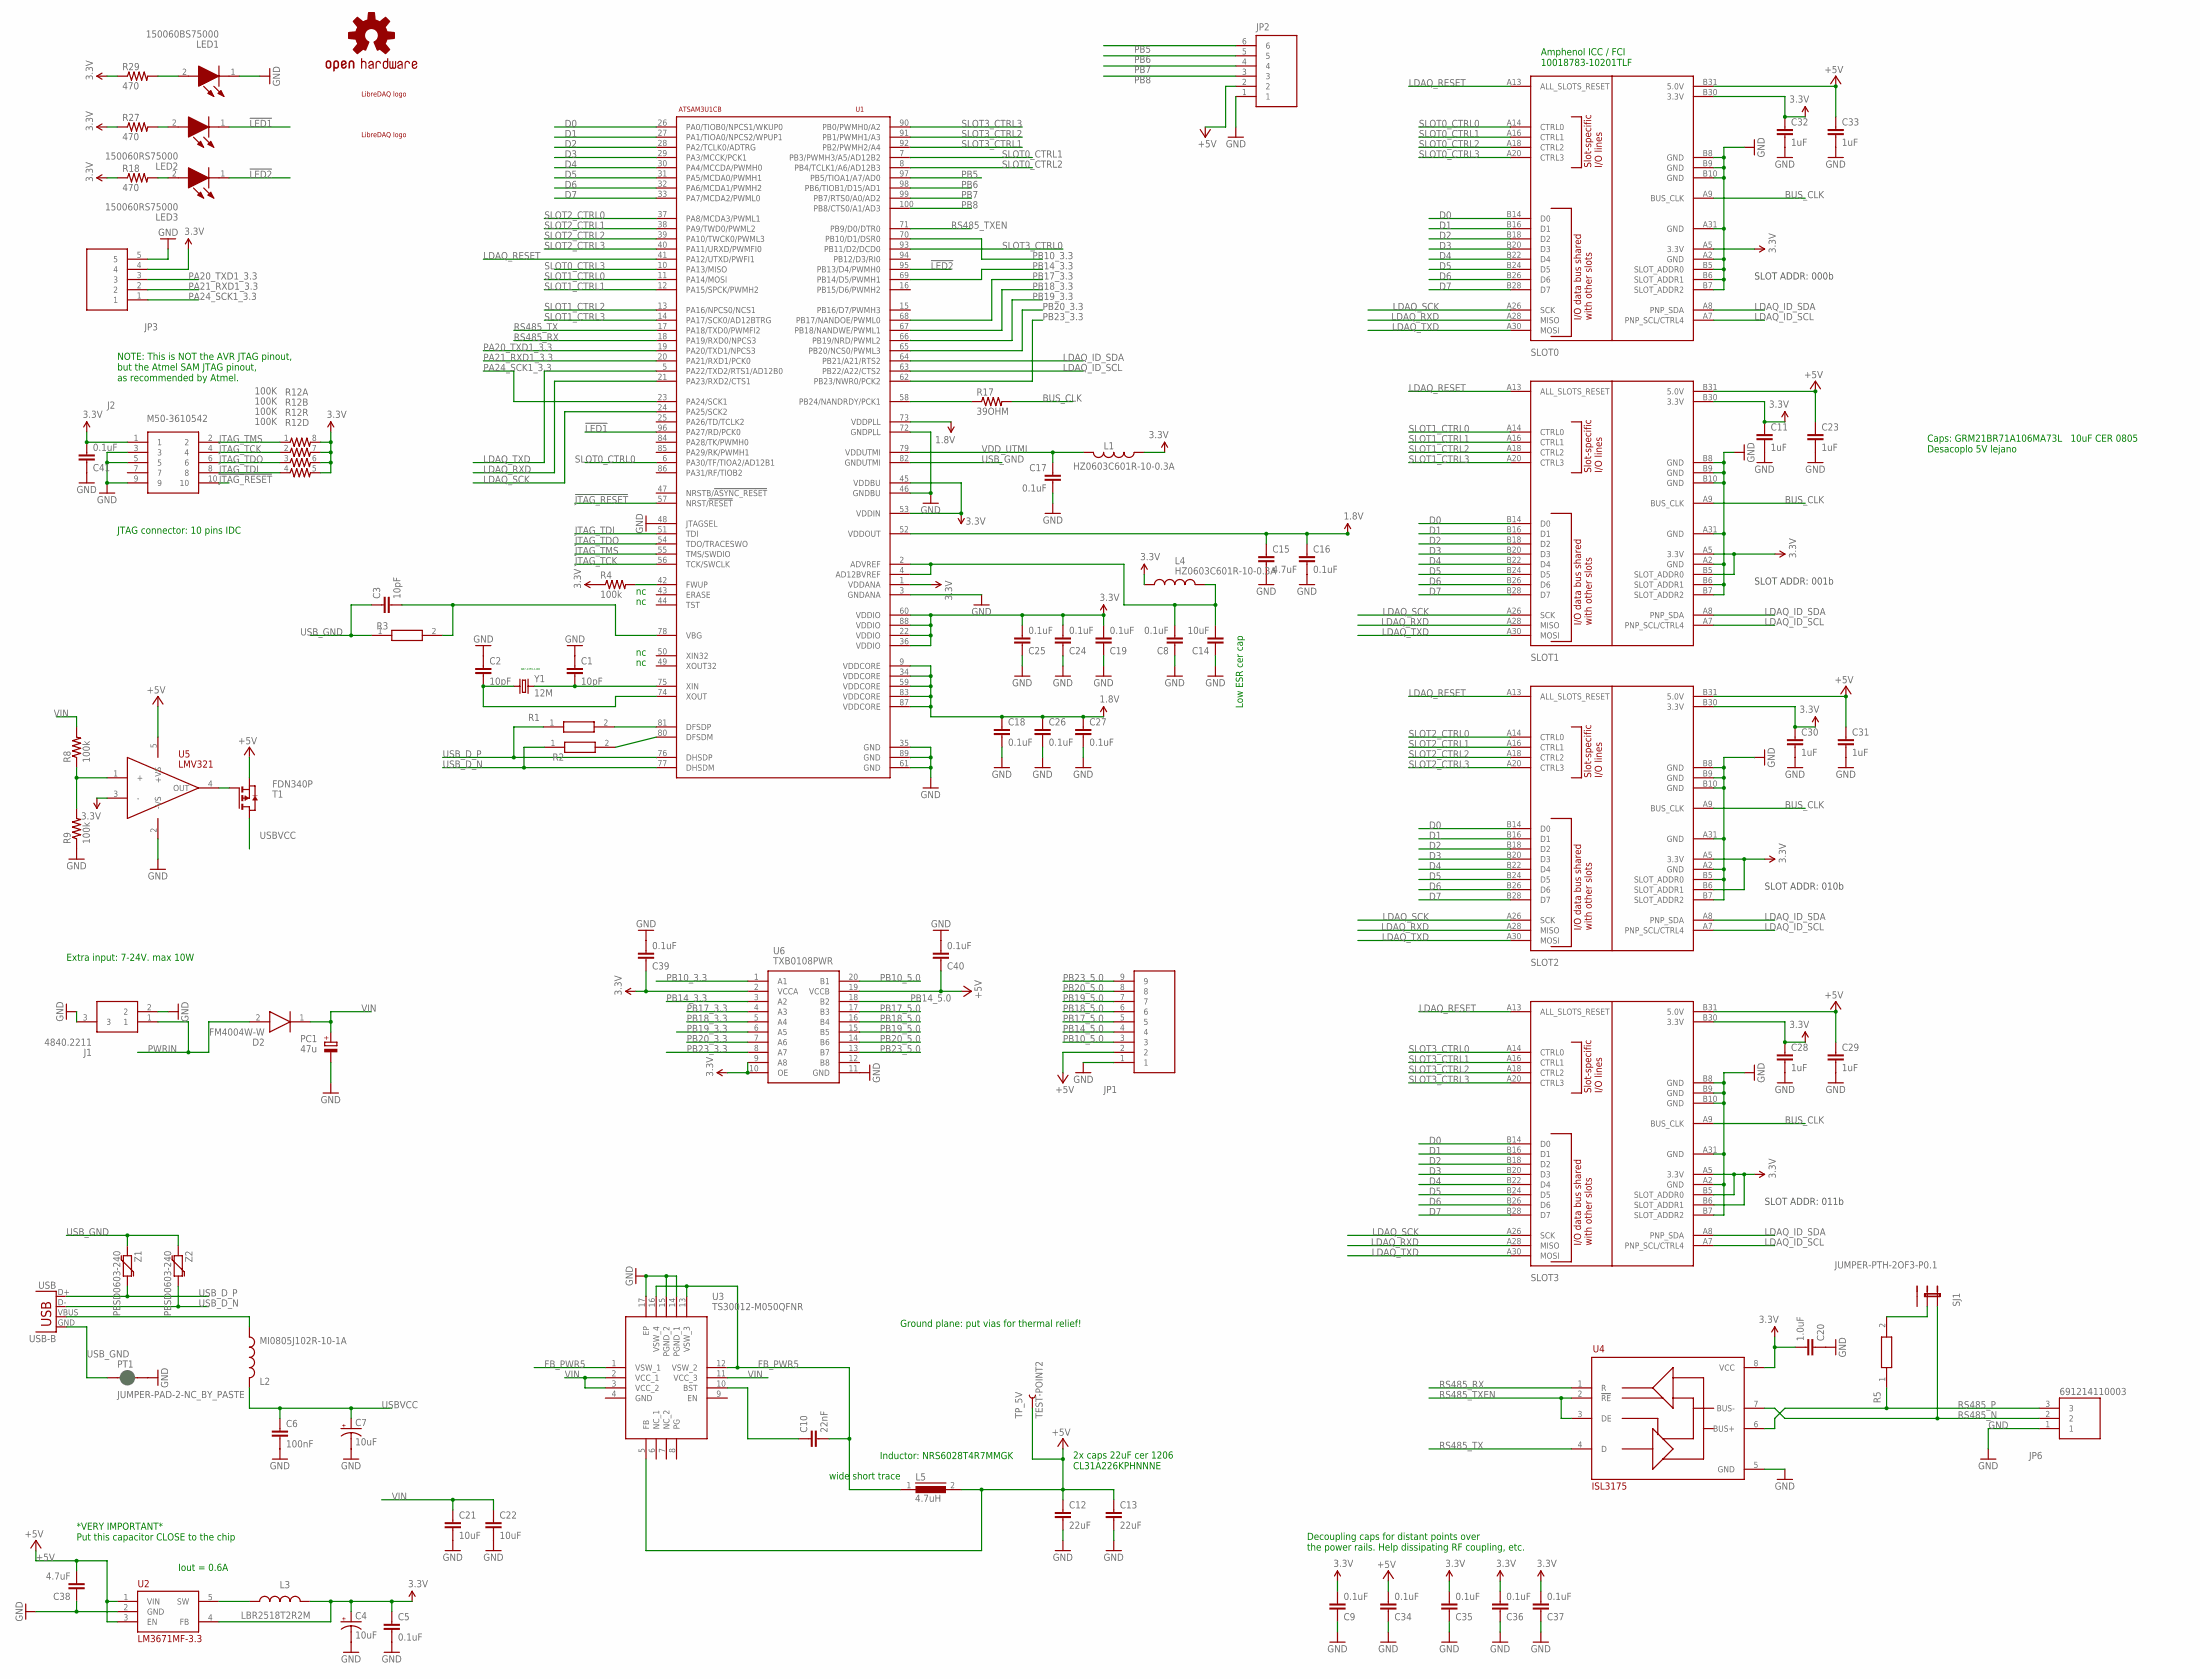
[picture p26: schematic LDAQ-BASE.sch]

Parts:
C1, C2, C3: 10pF; 0603-CAP
C4, C7: 10uF; EIA3216
C5, C8, C9, C16, C17, C18, C19, C24, C25, C26, C27, C34, C35, C36, C37, C39, C40, C41: 0.1uF; 0603-CAP
C6: 100nF; 0603-CAP
C10: 22nF; 0603-CAP
C11, C23, C28, C29, C30, C31, C32, C33: 1uF; 0805
C12, C13: 22uF; 1206
C14: 10uF; 0603-CAP
C15, C38: 4.7uF; 0603-CAP
C20: 1.0uF; 0603-CAP
C21, C22: 10uF; 1206
D2: FM4004W-W; DIOM5025X231N
J1: 4840.2211; 48402211
J2: M50-3610542; M503610542
JP1: 39357-0009; 393570009
JP2: 1984659
JP3: 1984646
JP6: 691214110003
L1, L4: HZ0603C601R-10-0.3A; 0603
L2: MI0805J102R-10-1A; 0805
L3: LBR2518T2R2M; 1007
L5: 4.7uH; INDUCTOR_6028
LED1: 150060BS75000; LEDC1608X80N
LED2, LED3: 150060RS75000; LEDC1608X80N
LOGO1: OSHW-LOGOL; OSHW-LOGO-L
PC1: 47u; PANASONIC_D
PT1: JUMPER-PAD-2-NC_BY_PASTE; PAD-JUMPER-2-NC_BY_PASTE_YES_SILK
R1, R2: CR1206-FX-39R0ELF; RESC3216X75N
R3: SFR03EZPF6801; RESC1608X55N
R4, R8, R9: 100k; 0603-RES
R5: CRCW0603120RFKEAC; RESC1608X55N
R12: 100K; 0603-ARV
R17: 39OHM; 0603@1
R18, R27, R29: 470; 0603-RES
SJ1: JUMPER-PTH-2OF3-P0.1; 1X03_LONGPADS
SLOT0, SLOT1, SLOT2, SLOT3: SLOT; PCI-E_64_PTH_CONN
T1: FDN340P; SOT-23
TP_5V: TEST-POINT2; PAD.02X.02
U1: ATSAM3U1CB; TQFP100
U2: LM3671MF-3.3; TOP23-5
U3: TS30012-M050QFNR; QFN50P300X300X100-17N
U4: ISL3175; SOIC8
U5: LMV321; SOT353-SC70-5
U6: TXB0108PWR; SOP65P640X120-20N
U$1: LIBREDAQ_LOGO_MINILOGO_GENERIC; LIBREDAQ_LOGO
U$6: LOGO_INDALO; LIBREDAQ_LOGO_INDALO_ALMERIA
USB: USB-B; USB-B-PTH
Y1: 12M; CRYSTAL-SMD-5X3
Z1, Z2: PESD0603-240; 0603-RES

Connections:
1.8V: C15.1, C16.1, C18.1, C26.1, C27.1, U1.9 (VDDCORE), U1.34 (VDDCORE), U1.52 (VDDOUT), U1.59 (VDDCORE), U1.73 (VDDPLL), U1.83 (VDDCORE), U1.87 (VDDCORE)
3.3V: C4.A (+), C5.1, C9.2, C11.1, C19.2, C20.2, C24.2, C25.2, C28.1, C30.1, C32.1, C35.2, C36.2, C37.2, C39.1, C41.2, J2.1, JP3.4, L1.2, L3.2, L4.1, R4.1, R12.5 (2), R12.6 (2), R12.7 (2), R12.8 (2), R18.1, R27.1, R29.1, SLOT0.A5 (3.3V), SLOT0.B30 (3.3V), SLOT1.A5 (3.3V), SLOT1.B5 (SLOT_ADDR0), SLOT1.B30 (3.3V), SLOT2.A5 (3.3V), SLOT2.B6 (SLOT_ADDR1), SLOT2.B30 (3.3V), SLOT3.A5 (3.3V), SLOT3.B5 (SLOT_ADDR0), SLOT3.B6 (SLOT_ADDR1), SLOT3.B30 (3.3V), U1.1 (VDDANA), U1.22 (VDDIO), U1.36 (VDDIO), U1.45 (VDDBU), U1.53 (VDDIN), U1.60 (VDDIO), U1.88 (VDDIO), U2.4 (FB), U4.8 (VCC), U5.3 (-), U6.2 (VCCA), U6.9 (A8), U6.10 (OE)
!JTAG_RESET: J2.10, U1.57 (NRST/!RESET)
!LED1: LED2.1 (K), U1.96 (PA27/RD/PCK0)
!LED2: LED3.1 (K), U1.95 (PB13/D4/PWMH0)
+5V: C12.1, C13.1, C23.1, C29.1, C31.1, C33.1, C34.2, C38.2, C40.1, JP1.2, JP2.2, L5.2, SLOT0.B31 (5.0V), SLOT1.B31 (5.0V), SLOT2.B31 (5.0V), SLOT3.B31 (5.0V), T1.2 (S), TP_5V.P$1, U2.1 (VIN), U2.3 (EN), U3.5 (FB), U5.5 (+VS), U6.19 (VCCB)
BUS_CLK: R17.2, SLOT0.A9 (BUS_CLK), SLOT1.A9 (BUS_CLK), SLOT2.A9 (BUS_CLK), SLOT3.A9 (BUS_CLK)
CMP: R8.1, R9.2, U5.1 (+)
D0: SLOT0.B14 (D0), SLOT1.B14 (D0), SLOT2.B14 (D0), SLOT3.B14 (D0), U1.26 (PA0/TIOB0/NPCS1/WKUP0)
D1: SLOT0.B16 (D1), SLOT1.B16 (D1), SLOT2.B16 (D1), SLOT3.B16 (D1), U1.27 (PA1/TIOA0/NPCS2/WPUP1)
D2: SLOT0.B18 (D2), SLOT1.B18 (D2), SLOT2.B18 (D2), SLOT3.B18 (D2), U1.28 (PA2/TCLK0/ADTRG)
D3: SLOT0.B20 (D3), SLOT1.B20 (D3), SLOT2.B20 (D3), SLOT3.B20 (D3), U1.29 (PA3/MCCK/PCK1)
D4: SLOT0.B22 (D4), SLOT1.B22 (D4), SLOT2.B22 (D4), SLOT3.B22 (D4), U1.30 (PA4/MCCDA/PWMH0)
D5: SLOT0.B24 (D5), SLOT1.B24 (D5), SLOT2.B24 (D5), SLOT3.B24 (D5), U1.31 (PA5/MCDA0/PWMH1)
D6: SLOT0.B26 (D6), SLOT1.B26 (D6), SLOT2.B26 (D6), SLOT3.B26 (D6), U1.32 (PA6/MCDA1/PWMH2)
D7: SLOT0.B28 (D7), SLOT1.B28 (D7), SLOT2.B28 (D7), SLOT3.B28 (D7), U1.33 (PA7/MCDA2/PWML0)
FB_PWR5: C10.2, L5.1, U3.1 (VSW_1), U3.12 (VSW_2), U3.13 (VSW_3), U3.16 (VSW_4)
GND: C1.1, C2.1, C4.C (-), C5.2, C6.2, C7.C (-), C8.1, C9.1, C11.2, C12.2, C13.2, C14.1, C15.2, C16.2, C17.2, C18.2, C19.1, C20.1, C21.2, C22.2, C23.2, C24.1, C25.1, C26.2, C27.2, C28.2, C29.2, C30.2, C31.2, C32.2, C33.2, C34.1, C35.1, C36.1, C37.1, C38.1, C39.2, C40.2, C41.1, J1.2, J1.3, J2.3, J2.5, J2.9, JP1.1, JP2.1, JP3.5, JP6.1, LED1.1 (K), PC1.-, PT1.2, R9.1, SLOT0.A2 (GND), SLOT0.A31 (GND), SLOT0.B5 (SLOT_ADDR0), SLOT0.B6 (SLOT_ADDR1), SLOT0.B7 (SLOT_ADDR2), SLOT0.B8 (GND), SLOT0.B9 (GND), SLOT0.B10 (GND), SLOT1.A2 (GND), SLOT1.A31 (GND), SLOT1.B6 (SLOT_ADDR1), SLOT1.B7 (SLOT_ADDR2), SLOT1.B8 (GND), SLOT1.B9 (GND), SLOT1.B10 (GND), SLOT2.A2 (GND), SLOT2.A31 (GND), SLOT2.B5 (SLOT_ADDR0), SLOT2.B7 (SLOT_ADDR2), SLOT2.B8 (GND), SLOT2.B9 (GND), SLOT2.B10 (GND), SLOT3.A2 (GND), SLOT3.A31 (GND), SLOT3.B7 (SLOT_ADDR2), SLOT3.B8 (GND), SLOT3.B9 (GND), SLOT3.B10 (GND), U1.3 (GNDANA), U1.35 (GND), U1.46 (GNDBU), U1.48 (JTAGSEL), U1.61 (GND), U1.72 (GNDPLL), U1.89 (GND), U2.2 (GND), U3.14 (PGND_1), U3.15 (PGND_2), U3.17 (EP), U4.5 (GND), U5.2 (-VS), U6.11 (GND)
JTAG_TCK: J2.4, R12.2 (1), U1.56 (TCK/SWCLK)
JTAG_TDI: J2.8, R12.4 (1), U1.51 (TDI)
JTAG_TDO: J2.6, R12.3 (1), U1.54 (TDO/TRACESWO)
JTAG_TMS: J2.2, R12.1, U1.55 (TMS/SWDIO)
LDAQ_ID_SCL: SLOT0.A7 (PNP_SCL/CTRL4), SLOT1.A7 (PNP_SCL/CTRL4), SLOT2.A7 (PNP_SCL/CTRL4), SLOT3.A7 (PNP_SCL/CTRL4), U1.63 (PB22/A22/CTS2)
LDAQ_ID_SDA: SLOT0.A8 (PNP_SDA), SLOT1.A8 (PNP_SDA), SLOT2.A8 (PNP_SDA), SLOT3.A8 (PNP_SDA), U1.64 (PB21/A21/RTS2)
LDAQ_RESET: SLOT0.A13 (ALL_SLOTS_RESET), SLOT1.A13 (ALL_SLOTS_RESET), SLOT2.A13 (ALL_SLOTS_RESET), SLOT3.A13 (ALL_SLOTS_RESET), U1.41 (PA12/UTXD/PWFI1)
LDAQ_RXD: SLOT0.A28 (MISO), SLOT1.A28 (MISO), SLOT2.A28 (MISO), SLOT3.A28 (MISO), U1.21 (PA23/RXD2/CTS1)
LDAQ_SCK: SLOT0.A26 (SCK), SLOT1.A26 (SCK), SLOT2.A26 (SCK), SLOT3.A26 (SCK), U1.24 (PA25/SCK2)
LDAQ_TXD: SLOT0.A30 (MOSI), SLOT1.A30 (MOSI), SLOT2.A30 (MOSI), SLOT3.A30 (MOSI), U1.5 (PA22/TXD2/RTS1/AD12B0)
unnamed: C1.2, U1.75 (XIN), Y1.3 (2)
unnamed: C2.2, U1.74 (XOUT), Y1.1
unnamed: R1.2, U1.81 (DFSDP)
unnamed: R2.2, U1.80 (DFSDM)
unnamed: C3.2, R3.2, U1.78 (VBG)
unnamed: R4.2, U1.42 (FWUP)
unnamed: L2.2, USB.VBUS
unnamed: L3.1, U2.5 (SW)
unnamed: R5.2, SJ1.2
unnamed: LED1.2 (A), R29.2
unnamed: C10.1, U3.10 (BST)
unnamed: T1.3 (G), U5.4 (OUT)
unnamed: R17.1, U1.58 (PB24/NANDRDY/PCK1)
unnamed: C8.2, C14.2, L4.2, U1.2 (ADVREF), U1.4 (AD12BVREF)
unnamed: LED2.2 (A), R27.2
unnamed: LED3.2 (A), R18.2
PA20_TXD1_3.3: JP3.3, U1.19 (PA20/TXD1/NPCS3)
PA21_RXD1_3.3: JP3.2, U1.20 (PA21/RXD1/PCK0)
PA24_SCK1_3.3: JP3.1, U1.23 (PA24/SCK1)
PB5: JP2.6, U1.97 (PB5/TIOA1/A7/AD0)
PB6: JP2.5, U1.98 (PB6/TIOB1/D15/AD1)
PB7: JP2.4, U1.99 (PB7/RTS0/A0/AD2)
PB8: JP2.3, U1.100 (PB8/CTS0/A1/AD3)
PB10_3.3: U1.70 (PB10/D1/DSR0), U6.1 (A1)
PB10_5.0: JP1.3, U6.20 (B1)
PB14_3.3: U1.69 (PB14/D5/PWMH1), U6.3 (A2)
PB14_5.0: JP1.4, U6.18 (B2)
PB17_3.3: U1.68 (PB17/NANDOE/PWML0), U6.4 (A3)
PB17_5.0: JP1.5, U6.17 (B3)
PB18_3.3: U1.67 (PB18/NANDWE/PWML1), U6.5 (A4)
PB18_5.0: JP1.6, U6.16 (B4)
PB19_3.3: U1.66 (PB19/NRD/PWML2), U6.6 (A5)
PB19_5.0: JP1.7, U6.15 (B5)
PB20_3.3: U1.65 (PB20/NCS0/PWML3), U6.7 (A6)
PB20_5.0: JP1.8, U6.14 (B6)
PB23_3.3: U1.62 (PB23/NWR0/PCK2), U6.8 (A7)
PB23_5.0: JP1.9, U6.13 (B7)
PWRIN: D2.2 (A), J1.1
RS485_N: JP6.2, SJ1.1, U4.7 (BUS-)
RS485_P: JP6.3, R5.1, U4.6 (BUS+)
RS485_RX: U1.18 (PA19/RXD0/NPCS3), U4.1 (R)
RS485_TX: U1.17 (PA18/TXD0/PWMFI2), U4.4 (D)
RS485_TXEN: U1.71 (PB9/D0/DTR0), U4.2 (!RE), U4.3 (DE)
SLOT0_CTRL0: SLOT0.A14 (CTRL0), U1.6 (PA30/TF/TIOA2/AD12B1)
SLOT0_CTRL1: SLOT0.A16 (CTRL1), U1.7 (PB3/PWMH3/A5/AD12B2)
SLOT0_CTRL2: SLOT0.A18 (CTRL2), U1.8 (PB4/TCLK1/A6/AD12B3)
SLOT0_CTRL3: SLOT0.A20 (CTRL3), U1.10 (PA13/MISO)
SLOT1_CTRL0: SLOT1.A14 (CTRL0), U1.11 (PA14/MOSI)
SLOT1_CTRL1: SLOT1.A16 (CTRL1), U1.12 (PA15/SPCK/PWMH2)
SLOT1_CTRL2: SLOT1.A18 (CTRL2), U1.13 (PA16/NPCS0/NCS1)
SLOT1_CTRL3: SLOT1.A20 (CTRL3), U1.14 (PA17/SCK0/AD12BTRG)
SLOT2_CTRL0: SLOT2.A14 (CTRL0), U1.37 (PA8/MCDA3/PWML1)
SLOT2_CTRL1: SLOT2.A16 (CTRL1), U1.38 (PA9/TWD0/PWML2)
SLOT2_CTRL2: SLOT2.A18 (CTRL2), U1.39 (PA10/TWCK0/PWML3)
SLOT2_CTRL3: SLOT2.A20 (CTRL3), U1.40 (PA11/URXD/PWMFI0)
SLOT3_CTRL0: SLOT3.A14 (CTRL0), U1.93 (PB11/D2/DCD0)
SLOT3_CTRL1: SLOT3.A16 (CTRL1), U1.92 (PB2/PWMH2/A4)
SLOT3_CTRL2: SLOT3.A18 (CTRL2), U1.91 (PB1/PWMH1/A3)
SLOT3_CTRL3: SLOT3.A20 (CTRL3), U1.90 (PB0/PWMH0/A2)
USBVCC: C6.1, C7.A (+), L2.1, T1.1 (D)
USB_D_N: R2.1, U1.77 (DHSDM), USB.D-, Z2.2
USB_D_P: R1.1, U1.76 (DHSDP), USB.D+, Z1.2
USB_GND: C3.1, PT1.1, R3.1, U1.82 (GNDUTMI), USB.GND, Z1.1, Z2.1
VDD_UTMI: C17.1, L1.1, U1.79 (VDDUTMI)
VIN: C21.1, C22.1, D2.1 (K), PC1.+, R8.2, U3.2 (VCC_1), U3.3 (VCC_2), U3.11 (VCC_3)

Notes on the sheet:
887-2355-1-ND
Low ESR cer cap
Caps: GRM21BR71A106MA73L 10uF CER 0805 Desacoplo 5V lejano
2x caps 22uF cer 1206 CL31A226KPHNNNE
Ground plane: put vias for thermal relief!
Inductor: NRS6028T4R7MMGK
Iout = 0.6A
Extra input: 7-24V. max 10W
wide short trace
SLOT ADDR: 000b
SLOT ADDR: 001b
SLOT ADDR: 010b
SLOT ADDR: 011b
Decoupling caps for distant points over the power rails. Help dissipating RF coupling, etc.
NOTE: This is NOT the AVR JTAG pinout, but the Atmel SAM JTAG pinout, as recommended by Atmel.
*VERY IMPORTANT* Put this capacitor CLOSE to the chip
JTAG connector: 10 pins IDC
Amphenol ICC / FCI 10018783-10201TLF

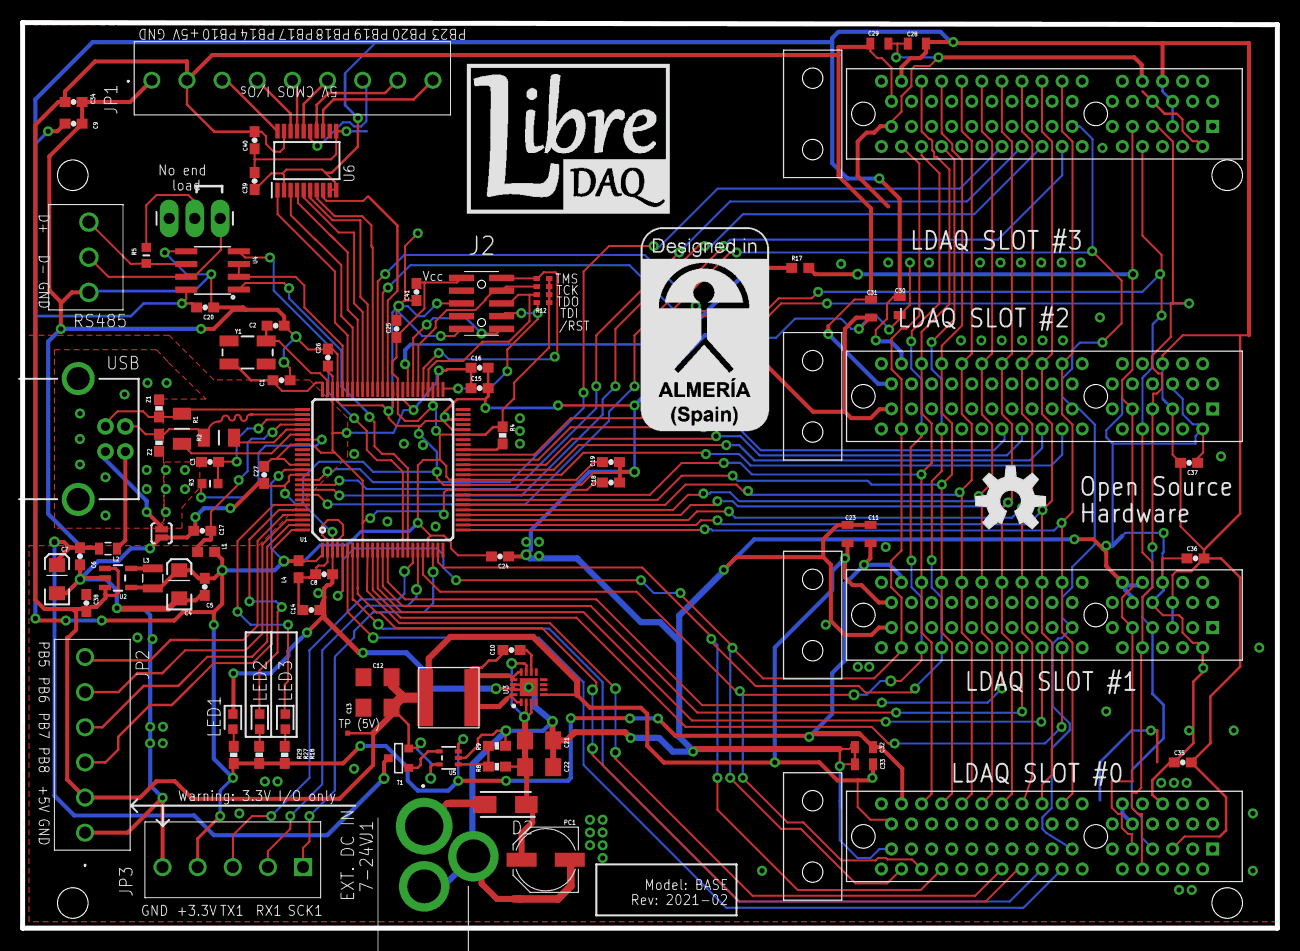
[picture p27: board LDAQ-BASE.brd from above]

Board: 2 copper layers, 125.0 x 90.2 mm, 94 parts (0 on the bottom side), 93 nets.

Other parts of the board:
U$2, U$3, U$4, U$5: STAND-OFF-TIGHT

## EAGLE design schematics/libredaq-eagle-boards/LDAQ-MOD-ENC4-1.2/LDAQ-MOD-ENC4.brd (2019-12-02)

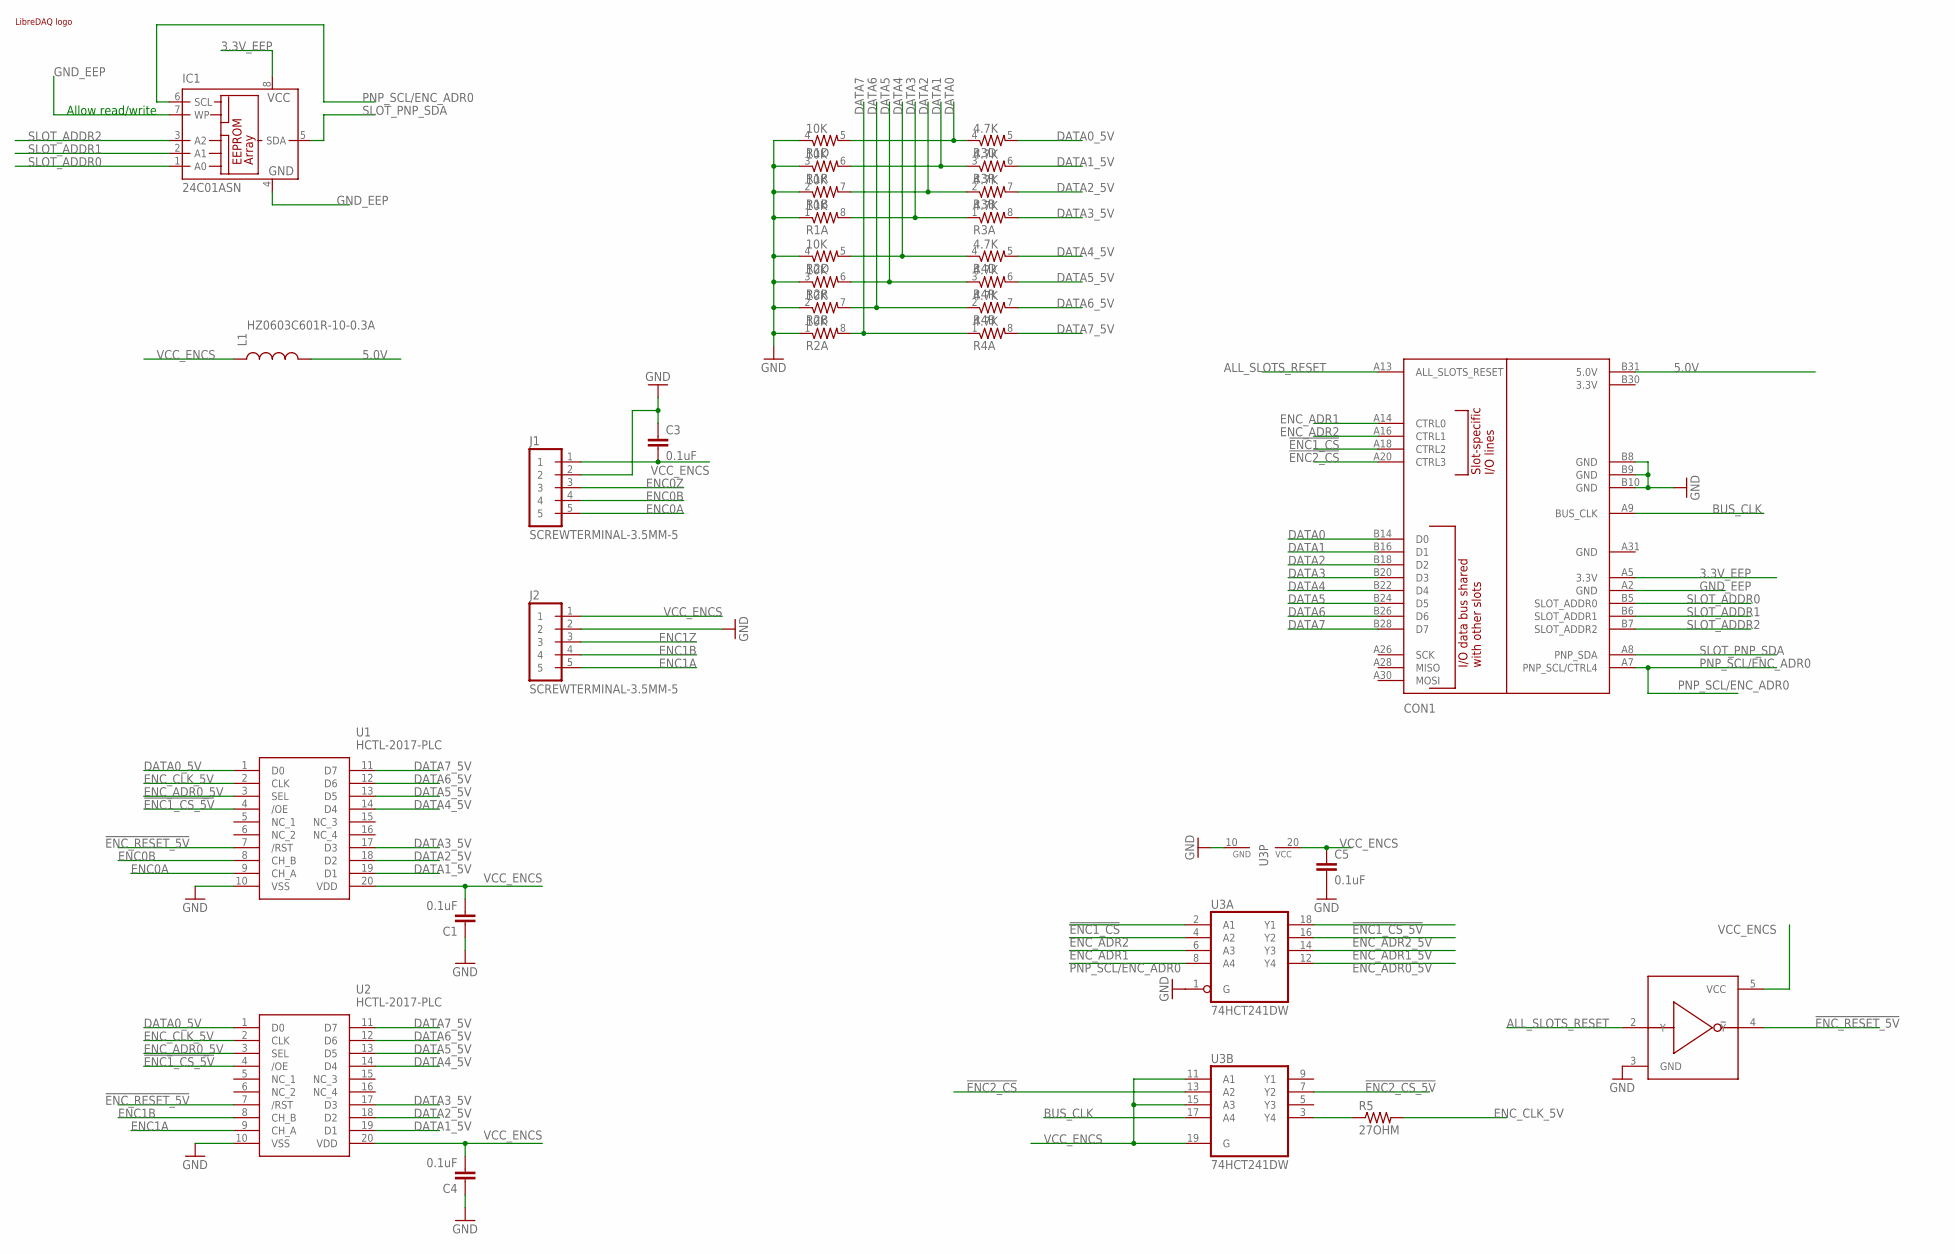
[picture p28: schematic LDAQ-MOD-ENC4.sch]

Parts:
C1, C3, C4, C5: 0.1uF; 0603-CAP
CON1: BOARD; PCI-E_64_EDGE_70X60_PADS-ONLY
IC1: 24C01ASN; SO-08
J1, J2: SCREWTERMINAL-3.5MM-5
L1: HZ0603C601R-10-0.3A; 0603
LOGO1: LIBREDAQ_LOGO_MINILOGO_GENERIC; LIBREDAQ_LOGO
R1, R2: 10K; 0603-ARV
R3, R4: 4.7K; 0603-ARV
R5: 27OHM; 0603
U1, U2: HCTL-2017-PLC; PLCC127P991X991X457-20N
U3: 74HCT241DW; SO20W
U4: 74AHCT1G04; SOT353-SC70-5

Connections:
3.3V_EEP: CON1.A5 (3.3V), IC1.8 (VCC)
5.0V: CON1.B31 (5.0V), L1.2
!ENC1_CS: CON1.A18 (CTRL2), U3.2 (A1)
!ENC1_CS_5V: U1.4 (/OE), U2.4 (/OE), U3.18 (Y1)
!ENC2_CS: CON1.A20 (CTRL3), U3.13 (A2)
!ENC2_CS_5V: U3.7 (Y2)
!ENC_RESET_5V: U1.7 (/RST), U2.7 (/RST), U4.4 (!Y)
ALL_SLOTS_RESET: CON1.A13 (ALL_SLOTS_RESET), U4.2 (Y)
BUS_CLK: CON1.A9 (BUS_CLK), U3.17 (A4)
DATA0: CON1.B14 (D0), R1.5 (2), R3.4 (1)
DATA0_5V: R3.5 (2), U1.1 (D0), U2.1 (D0)
DATA1: CON1.B16 (D1), R1.6 (2), R3.3 (1)
DATA1_5V: R3.6 (2), U1.19 (D1), U2.19 (D1)
DATA2: CON1.B18 (D2), R1.7 (2), R3.2 (1)
DATA2_5V: R3.7 (2), U1.18 (D2), U2.18 (D2)
DATA3: CON1.B20 (D3), R1.8 (2), R3.1
DATA3_5V: R3.8 (2), U1.17 (D3), U2.17 (D3)
DATA4: CON1.B22 (D4), R2.5 (2), R4.4 (1)
DATA4_5V: R4.5 (2), U1.14 (D4), U2.14 (D4)
DATA5: CON1.B24 (D5), R2.6 (2), R4.3 (1)
DATA5_5V: R4.6 (2), U1.13 (D5), U2.13 (D5)
DATA6: CON1.B26 (D6), R2.7 (2), R4.2 (1)
DATA6_5V: R4.7 (2), U1.12 (D6), U2.12 (D6)
DATA7: CON1.B28 (D7), R2.8 (2), R4.1
DATA7_5V: R4.8 (2), U1.11 (D7), U2.11 (D7)
ENC0A: J1.5, U1.9 (CH_A)
ENC0B: J1.4, U1.8 (CH_B)
ENC0Z: J1.3
ENC1A: J2.5, U2.9 (CH_A)
ENC1B: J2.4, U2.8 (CH_B)
ENC1Z: J2.3
ENC_ADR0_5V: U1.3 (SEL), U2.3 (SEL), U3.12 (Y4)
ENC_ADR1: CON1.A14 (CTRL0), U3.6 (A3)
ENC_ADR1_5V: U3.14 (Y3)
ENC_ADR2: CON1.A16 (CTRL1), U3.4 (A2)
ENC_ADR2_5V: U3.16 (Y2)
ENC_CLK_5V: R5.2, U1.2 (CLK), U2.2 (CLK)
GND: C1.1, C3.1, C4.1, C5.2, CON1.B8 (GND), CON1.B9 (GND), CON1.B10 (GND), J1.2, J2.2, R1.1, R1.2 (1), R1.3 (1), R1.4 (1), R2.1, R2.2 (1), R2.3 (1), R2.4 (1), U1.10 (VSS), U2.10 (VSS), U3.1 (G), U3.10 (GND), U4.3 (GND)
GND_EEP: CON1.A2 (GND), IC1.4 (GND), IC1.7 (WP)
unnamed: R5.1, U3.3 (Y4)
PNP_SCL/ENC_ADR0: CON1.A7 (PNP_SCL/CTRL4), IC1.6 (SCL), U3.8 (A4)
SLOT_ADDR0: CON1.B5 (SLOT_ADDR0), IC1.1 (A0)
SLOT_ADDR1: CON1.B6 (SLOT_ADDR1), IC1.2 (A1)
SLOT_ADDR2: CON1.B7 (SLOT_ADDR2), IC1.3 (A2)
SLOT_PNP_SDA: CON1.A8 (PNP_SDA), IC1.5 (SDA)
VCC_ENCS: C1.2, C3.2, C4.2, C5.1, J1.1, J2.1, L1.1, U1.20 (VDD), U2.20 (VDD), U3.11 (A1), U3.15 (A3), U3.19 (G), U3.20 (VCC), U4.5 (VCC)

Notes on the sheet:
Allow read/write

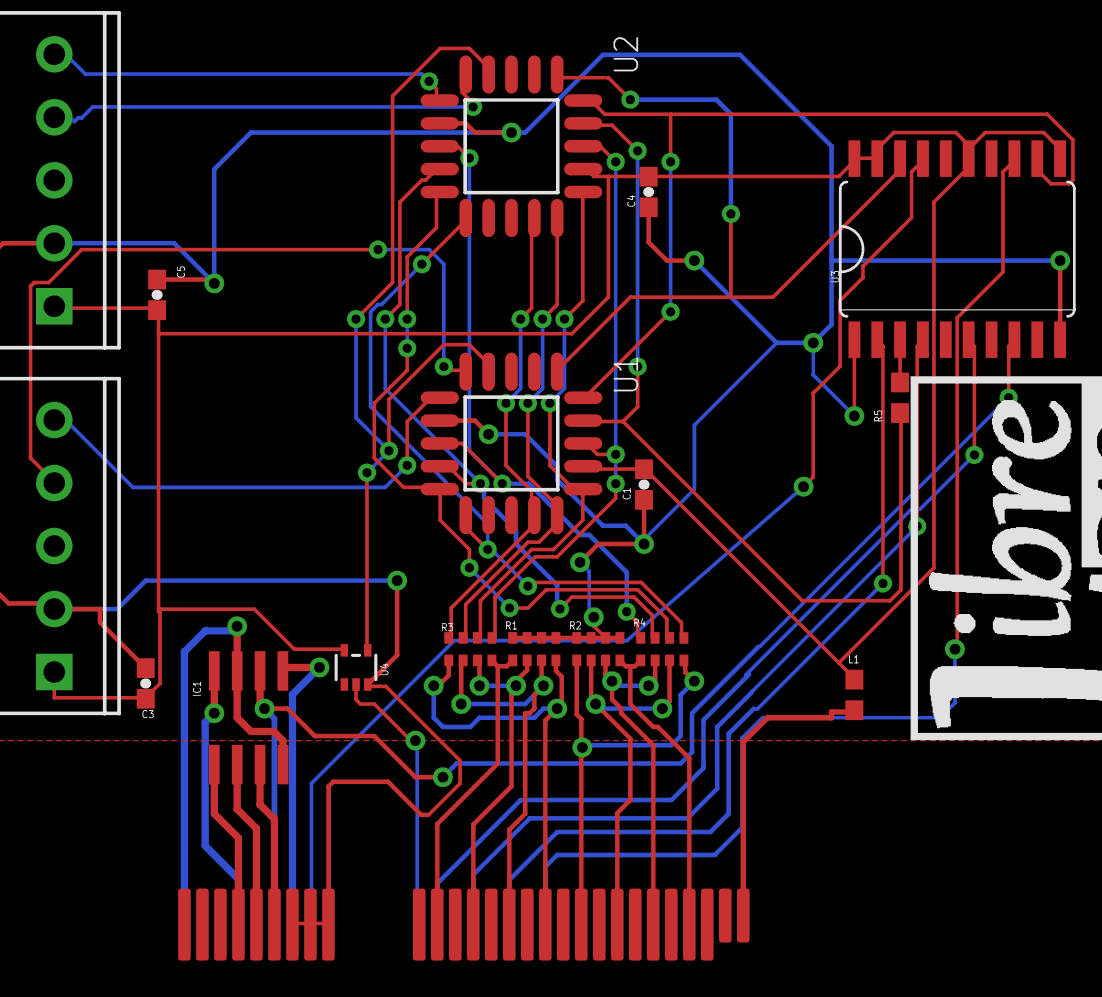
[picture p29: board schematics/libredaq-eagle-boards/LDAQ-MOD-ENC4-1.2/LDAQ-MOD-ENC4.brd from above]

Board: 2 copper layers, 19 parts (0 on the bottom side), 41 nets.

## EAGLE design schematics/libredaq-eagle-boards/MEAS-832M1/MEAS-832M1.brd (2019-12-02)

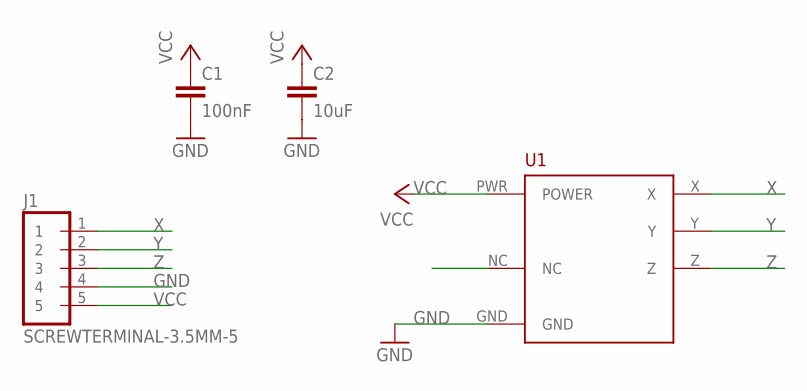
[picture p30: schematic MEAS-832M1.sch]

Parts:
C1: 100nF; C0805K
C2: 10uF; C0805K
J1: SCREWTERMINAL-3.5MM-5
U1: MEAS-832M1

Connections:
GND: C1.2, C2.2, J1.4, U1.GND
VCC: C1.1, C2.1, J1.5, U1.PWR (POWER)
X: J1.1, U1.X
Y: J1.2, U1.Y
Z: J1.3, U1.Z

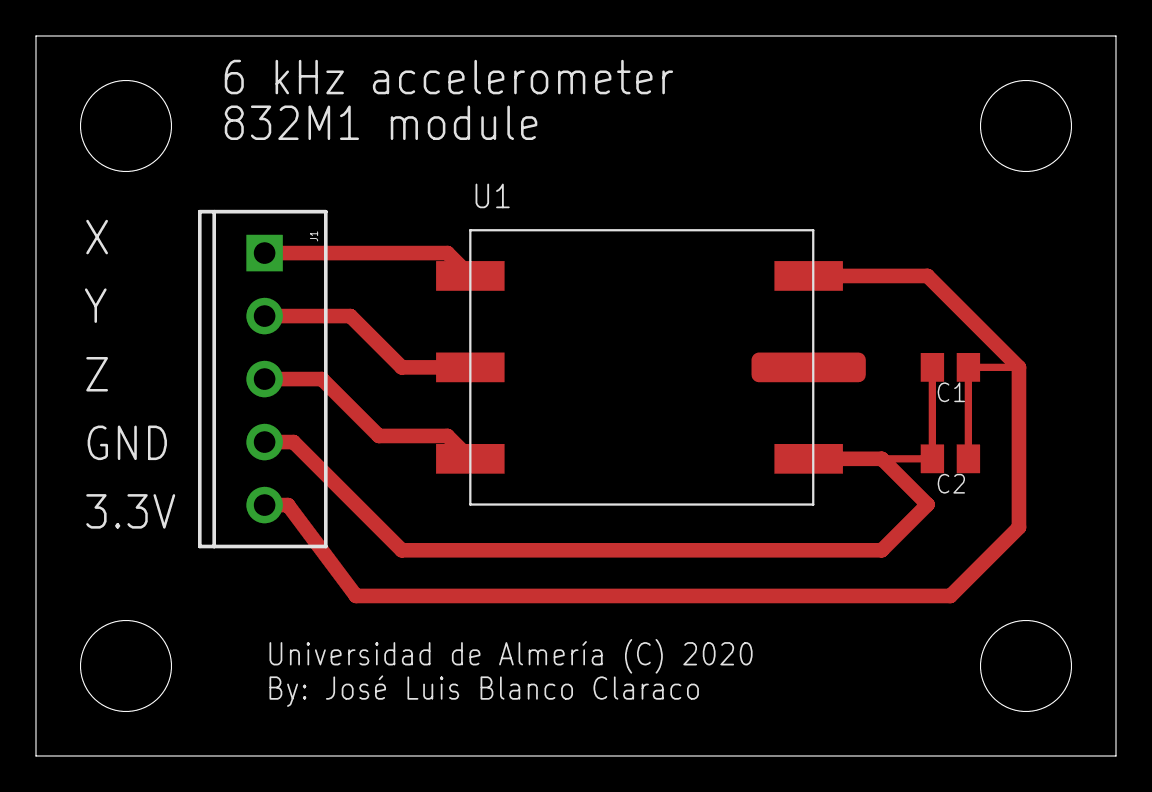
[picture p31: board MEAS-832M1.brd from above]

Board: 2 copper layers, 60.0 x 40.0 mm, 4 parts (0 on the bottom side), 5 nets.

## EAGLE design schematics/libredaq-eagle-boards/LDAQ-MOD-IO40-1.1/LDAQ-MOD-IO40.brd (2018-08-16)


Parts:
C1: 100nF; 0603-CAP
C2: 10uF; EIA3216
CON1: C1; PCI-E_64_EDGE_70X60_PADS-ONLY
JP1: J1; 2X5-SHROUDED
JP2: J2; 2X10-SHROUDED
JP3: J3; 2X10-SHROUDED
JP4: J4; 1X04
L1: HZ0603C601R-10-0.3A; 0603
LOGO1: LIBREDAQ_LOGO_MINILOGO_GENERIC; LIBREDAQ_LOGO
LOGO2: OSHW-LOGOM; OSHW-LOGO-M
Q1, Q2: FDV301N; SOT23-3
R1, R2, R3, R4: 4.7K; 0603-RES
U1: CY8C9540A; SSOP-48
U2: 24C01ASN; SO-08

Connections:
3.3V: CON1.B30 (3.3V), Q1.1 (G), Q2.1 (G), R1.1, R2.1
3.3V_EEP: CON1.A5 (3.3V), U2.8 (VCC)
5V: CON1.B31 (5.0V), JP4.2, L1.2, R3.1, R4.1
ALL_SLOTS_RESET: CON1.A13 (ALL_SLOTS_RESET), U1.35 (RESET)
GND: C1.2, C2.C (-), CON1.A31 (GND), CON1.B8 (GND), CON1.B9 (GND), CON1.B10 (GND), JP1.9, JP2.1, JP2.3, JP3.17, JP3.19, JP4.1, U1.13 (GND), U1.23 (A0), U1.24 (GND)
GND_EEP: CON1.A2 (GND), U2.4 (GND), U2.7 (WP)
P00: JP3.15, U1.1 (P0.0_PWM7)
P01: JP3.13, U1.2 (P0.1_PWM5)
P02: JP3.11, U1.3 (P0.2_PWM3)
P03: JP3.9, U1.4 (P0.3_PWM1)
P04: JP3.7, U1.5 (P0.4_PWM7)
P05: JP3.5, U1.6 (P0.5_PWM5)
P06: JP3.3, U1.7 (P0.6_PWM3)
P07: JP3.1, U1.8 (P0.7_PWM1)
P10: JP3.16, U1.47 (P1.0_PWM6)
P11: JP3.14, U1.46 (P1.1_PWM4)
P12: JP3.12, U1.45 (P1.2_PWM2)
P13: JP3.10, U1.44 (P1.3_PWM0)
P14: JP3.8, U1.43 (P1.4_PWM6)
P15: JP3.6, U1.42 (P1.5_PWM4)
P16: JP3.4, U1.41 (P1.6_PWM2)
P17: JP3.2, U1.40 (P1.7_PWM0)
P20: JP2.15, U1.28 (P2.0_PWM6)
P21: JP2.17, U1.27 (P2.1_PWM4)
P22: JP2.19, U1.25 (P2.2_PWM0)
P23: JP2.13, U1.22 (P2.3_PWM3)
P30: JP1.2, U1.9 (P3.0_PWM7)
P31: JP1.4, U1.10 (P3.1_PWM5)
P32: JP1.6, U1.11 (P3.2_PWM3)
P33: JP1.8, U1.12 (P3.3_PWM1)
P34: JP1.1, U1.14 (P3.4_PWM7)
P35: JP1.3, U1.15 (P3.5_PWM5)
P36: JP1.5, U1.16 (P3.6_PWM3)
P37: JP1.7, U1.17 (P3.7_PWM1)
P40: JP2.2, U1.39 (P4.0_PWM6)
P41: JP2.4, U1.38 (P4.1_PWM4)
P42: JP2.6, U1.37 (P4.2_PWM2)
P43: JP2.8, U1.36 (P4.3_PWM0)
P44: JP2.10, U1.34 (P4.4_PWM6)
P45: JP2.12, U1.33 (P4.5_PWM4)
P46: JP2.14, U1.32 (P4.6_PWM2)
P47: JP2.16, U1.31 (P4.7_PWM0)
P50: JP2.18, U1.30 (P5.0_PWM2)
P51: JP2.20, U1.29 (P5.1_PWM0)
P52: JP2.9, U1.18 (P5.2_PWM3)
P53: JP2.11, U1.19 (P5.3_PWM1)
SCL: JP4.4, Q1.3 (D), R3.2, U1.20 (SCL)
SCL_3.3: CON1.A14 (CTRL0), Q1.2 (S), R1.2
SDA: JP4.3, Q2.3 (D), R4.2, U1.21 (SDA)
SDA_3.3: CON1.A16 (CTRL1), Q2.2 (S), R2.2
SLOT_ADDR0: CON1.B5 (SLOT_ADDR0), U2.1 (A0)
SLOT_ADDR1: CON1.B6 (SLOT_ADDR1), U2.2 (A1)
SLOT_ADDR2: CON1.B7 (SLOT_ADDR2), U2.3 (A2)
SLOT_PNP_SCL: CON1.A7 (PNP_SCL/CTRL4), U2.6 (SCL)
SLOT_PNP_SDA: CON1.A8 (PNP_SDA), U2.5 (SDA)
VCC: C1.1, C2.A (+), JP1.10, JP2.5, JP2.7, JP3.18, JP3.20, L1.1, U1.48 (VDD)

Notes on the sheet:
Allow read/write


Board: 2 copper layers, 18 parts (0 on the bottom side), 56 nets.

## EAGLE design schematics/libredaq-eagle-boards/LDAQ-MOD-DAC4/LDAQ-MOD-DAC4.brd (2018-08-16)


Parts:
C1, C3, C4: 1.0uF; 0603-CAP
C2, C5: 0.1uF; 0603-CAP
C6: 10uF; EIA3216
CON1: BOARD; PCI-E_64_EDGE_63X50_PADS-ONLY
J1: SCREWTERMINAL-3.5MM-5
J2: STANDALONE; 1X05_LOCK
L1: HZ0603C601R-10-0.3A; 0603
LOGO1: OSHW-LOGOL; OSHW-LOGO-L
Q1, Q2, Q3: FDV301N; SOT23-3
R1, R2, R3, R5, R6, R9, R10, R11: 10K; 0603-RES
R4: 100k; 0603-RES
R7, R8: 10K; 0603-ARV
SJ2: JUMPER-PAD-2-NC_BY_PASTE; PAD-JUMPER-2-NC_BY_PASTE_YES_SILK
U1: OPA336NJ; SOT23-5
U2: MAX5500; SSOP20
U3: 24C01ASN; SO-08
U$1: LIBREDAQ_LOGO_MINILOGO_GENERIC; LIBREDAQ_LOGO

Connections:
3.3V: CON1.B30 (3.3V), Q1.1 (G), Q2.1 (G), Q3.1 (G), R5.1, R6.1, R11.1
3.3V_EEP: CON1.A5 (3.3V), U3.8 (VCC)
5V: C6.A (+), CON1.B31 (5.0V), J2.5, L1.2, R3.1, R9.1, R10.1
/CS: J2.2, Q3.3 (D), R3.2, U2.8 (!CS)
/CS_3.3: CON1.A14 (CTRL0), Q3.2 (S), R11.2
AGND: C1.2, C2.2, C3.2, C4.2, C5.2, J1.1, R2.1, R7.2 (1), R7.3 (1), R8.2 (1), R8.3 (1), SJ2.2, U1.2 (-VS), U2.1 (AGND), U2.11 (DGND)
AOUT0: J1.2, R7.1, U2.3 (OUTA)
AOUT1: J1.3, R7.4 (1), U2.4 (OUTB)
AOUT2: J1.4, R8.1, U2.17 (OUTC)
AOUT3: J1.5, R8.4 (1), U2.18 (OUTD)
DAC_DIN: J2.3, Q1.3 (D), R9.2, U2.9 (DIN)
DAC_DIN_3.3: CON1.A30 (MOSI), Q1.2 (S), R5.2
DAC_SCK: J2.4, Q2.3 (D), R10.2, U2.10 (SCLK)
DAC_SCK_3.3: CON1.A26 (SCK), Q2.2 (S), R6.2
GND: C6.C (-), CON1.A31 (GND), CON1.B9 (GND), CON1.B10 (GND), J2.1, SJ2.1
GND_EEP: CON1.B8 (GND), U3.4 (GND), U3.7 (WP)
unnamed: R7.7 (2), R7.8 (2), U2.2 (FBA)
unnamed: C1.1, R4.1, U2.7 (!CL)
unnamed: R7.5 (2), R7.6 (2), U2.5 (FBB)
unnamed: R8.7 (2), R8.8 (2), U2.16 (FBC)
unnamed: R8.5 (2), R8.6 (2), U2.19 (FBD)
unnamed: C3.1, R1.1, R2.2, U1.3 (+)
REF_VOLT: U1.1 (OUT), U1.4 (-), U2.6 (REFAB), U2.15 (REFCD)
SLOT_ADDR0: CON1.B5 (SLOT_ADDR0), U3.1 (A0)
SLOT_ADDR1: CON1.B6 (SLOT_ADDR1), U3.2 (A1)
SLOT_ADDR2: CON1.B7 (SLOT_ADDR2), U3.3 (A2)
SLOT_PNP_SCL: CON1.A7 (PNP_SCL/CTRL4), U3.6 (SCL)
SLOT_PNP_SDA: CON1.A8 (PNP_SDA), U3.5 (SDA)
VCC: C2.1, C4.1, C5.1, L1.1, R1.2, R4.2, U1.5 (+VS), U2.20 (VDD)

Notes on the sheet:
Allow read/write
Connector for standalone usage (out of a LDAQ BASE)


Board: 2 copper layers, 30 parts (0 on the bottom side), 29 nets.

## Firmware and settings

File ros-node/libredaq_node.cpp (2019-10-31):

/*********************************************************************
 * Software License Agreement (BSD License)
 *
 *  ROS driver for LibreDAQ
 *  Copyright (c) 2018, Jose Luis Blanco Claraco
 *  All rights reserved.
 *
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
 *   * Redistributions of source code must retain the above copyright
 *     notice, this list of conditions and the following disclaimer.
 *   * Redistributions in binary form must reproduce the above
 *     copyright notice, this list of conditions and the following
 *     disclaimer in the documentation and/or other materials provided
 *     with the distribution.
 *
 *  THIS SOFTWARE IS PROVIDED BY THE COPYRIGHT HOLDERS AND CONTRIBUTORS
 *  "AS IS" AND ANY EXPRESS OR IMPLIED WARRANTIES, INCLUDING, BUT NOT
 *  LIMITED TO, THE IMPLIED WARRANTIES OF MERCHANTABILITY AND FITNESS
 *  FOR A PARTICULAR PURPOSE ARE DISCLAIMED. IN NO EVENT SHALL THE
 *  COPYRIGHT OWNER OR CONTRIBUTORS BE LIABLE FOR ANY DIRECT, INDIRECT,
 *  INCIDENTAL, SPECIAL, EXEMPLARY, OR CONSEQUENTIAL DAMAGES (INCLUDING,
 *  BUT NOT LIMITED TO, PROCUREMENT OF SUBSTITUTE GOODS OR SERVICES;
 *  LOSS OF USE, DATA, OR PROFITS; OR BUSINESS INTERRUPTION) HOWEVER
 *  CAUSED AND ON ANY THEORY OF LIABILITY, WHETHER IN CONTRACT, STRICT
 *  LIABILITY, OR TORT (INCLUDING NEGLIGENCE OR OTHERWISE) ARISING IN
 *  ANY WAY OUT OF THE USE OF THIS SOFTWARE, EVEN IF ADVISED OF THE
 *  POSSIBILITY OF SUCH DAMAGE.
 *********************************************************************/

#include <cstdlib>
#include <libredaq.h>
#include <mutex>
#include <numeric> // std::accumulate()
#include <ros/ros.h>
#include <sstream>
#include <std_msgs/String.h>
#include <stdio.h>
#include <vector>

#include "libredaq/EncoderDecimatedSpeed.h"
#include <sensor_msgs/JointState.h>

// (Default=20 Hz) Rate for publishing encoder states
double PUBLISH_RATE = 20; // [Hz]
// (Default=10) Number of samples for the sliding window average filter of
// speeds.
int SPEED_FILTER_SAMPLES_LEN = 10;
// (Default=1) Number of "ITERATE" loops without any new encoder tick before
// resetting the filtered average velocities.
int SPEED_FILTER_IDLE_ITER_LOOPS_BEFORE_RESET = 1;

struct TStatePerChannel {
  int tickPos = .0;
  double instantaneousSpeed = .0;
  std::vector<double> speeds_buffer;
  bool speed_buffer_updated = false;
  unsigned int loops_without_update_speed_buffer = 0;
};
std::vector<TStatePerChannel> encoder_states;
std::mutex encoder_states_mux;

// Callback for ENCODERS data
void my_callback_ENC(const libredaq::TCallbackData_ENC &data) {
  std::lock_guard<std::mutex> lock(encoder_states_mux);

  static double last_tim = .0;
  const double At = data.device_timestamp - last_tim;
  last_tim = data.device_timestamp;
  const double At_inv = At > .0 ? 1.0 / At : .0;

  const size_t NUM_ENCODERS =
      sizeof(data.enc_ticks) / sizeof(data.enc_ticks[0]);
  encoder_states.resize(NUM_ENCODERS);
  for (size_t i = 0; i < NUM_ENCODERS; i++) {
    TStatePerChannel &spc = encoder_states[i];
    const auto positionChange = data.enc_ticks[i] - spc.tickPos;
    spc.tickPos = data.enc_ticks[i];

    spc.instantaneousSpeed = positionChange * At_inv;
    spc.speeds_buffer.push_back(spc.instantaneousSpeed);
    spc.speed_buffer_updated = true;
    spc.loops_without_update_speed_buffer = 0;
  }

  ROS_INFO_THROTTLE(
      0.5, "TIME: %15.7f CALLBACK=%6.03f Hz ENCODERS: %8f %8f %8f %8f\n",
      data.device_timestamp, At_inv, (double)data.enc_ticks[0],
      (double)data.enc_ticks[1], (double)data.enc_ticks[2],
      (double)data.enc_ticks[3]);
}

int main(int argc, char *argv[]) {
  try {

    ros::init(argc, argv, "libredaq");
    ros::NodeHandle n;
    ros::NodeHandle nh("~");

    std::vector<std::string> joint_names = {"joint0", "joint1", "joint2",
                                            "joint3"};
    std::vector<double> joint_tick2rad = {4, 1.0};
    for (unsigned int i = 0; i < joint_names.size(); i++) {
      char str[100];
      sprintf(str, "joint%u_name", i);
      nh.getParam(str, joint_names[i]);

      sprintf(str, "joint%u_tick2rad", i);
      nh.getParam(str, joint_tick2rad[i]);

      ROS_INFO("Channel %u: '%s'='%s'", i, str, joint_names[i].c_str());
    }

    std::string serial_port = "ttyACM0";
    nh.getParam("serial_port", serial_port);

    std::string frame_id;
    nh.getParam("frame_id", frame_id);
    nh.getParam("PUBLISH_RATE", PUBLISH_RATE);
    nh.getParam("SPEED_FILTER_SAMPLES_LEN", SPEED_FILTER_SAMPLES_LEN);
    nh.getParam("SPEED_FILTER_IDLE_ITER_LOOPS_BEFORE_RESET",
                SPEED_FILTER_IDLE_ITER_LOOPS_BEFORE_RESET);

    ROS_INFO("frame_id = '%s'", frame_id.c_str());
    ROS_INFO("SPEED_FILTER_SAMPLES_LEN = %i", SPEED_FILTER_SAMPLES_LEN);
    ROS_INFO("PUBLISH_RATE = %f", PUBLISH_RATE);

    // First time: create publishers:
    const std::string topic_path = "joint_states";
    ROS_INFO("Publishing state to topic: %s", topic_path.c_str());

    ros::Publisher encoder_pub =
        n.advertise<sensor_msgs::JointState>(topic_path, 100);
    std::vector<ros::Publisher> encoder_decimspeed_pubs;

    // Declare the object that represents one LibreDAQ physical device
    libredaq::Device daq;

    // Establish communications:
    daq.connect_serial_port(serial_port);
    //    ROS_ERROR("Problem waiting for attachment: %s", sError.c_str());
    //    return 1; // !=0 exit status means error in main()

    daq.set_callback_ENC(&my_callback_ENC);

    printf("Starting ENCODERS task...\n");
    daq.start_task_encoders(PUBLISH_RATE * 100);

    ros::Rate rate(PUBLISH_RATE);
    ROS_INFO("Publishing encoder states at %.03f Hz", PUBLISH_RATE);
    while (ros::ok()) {
      ros::spinOnce();
      rate.sleep();

      // Publish:
      {
        std::lock_guard<std::mutex> lock(encoder_states_mux);
        const unsigned int N = encoder_states.size();

        // First time? We need to create decimated speed publisher here,
        // once we know how many channel we have. Also, they must be independent
        // for each channel due to the unsynchronous nature of the filtering
        // algorithm:
        if (encoder_decimspeed_pubs.size() != N) {
          encoder_decimspeed_pubs.resize(N);
          for (unsigned int i = 0; i < N; i++) {
            std::string s = topic_path;
            char buf[100];
            sprintf(buf, "_ch%u_decim_speed", i);
            s += buf;
            ROS_INFO("Publishing decimated speed of channel %u to topic: %s", i,
                     s.c_str());
            encoder_decimspeed_pubs[i] =
                n.advertise<libredaq::EncoderDecimatedSpeed>(s, 10);
          }
        }

        sensor_msgs::JointState js_msg;
        static uint32_t seq_cnt = 0;
        js_msg.header.seq = (seq_cnt++);
        js_msg.header.stamp = ros::Time::now();
        js_msg.header.frame_id = frame_id;

        js_msg.name.resize(N);
        for (unsigned int i = 0; i < std::min<size_t>(joint_names.size(), N);
             i++)
          js_msg.name[i] = joint_names[i];

        js_msg.position.resize(N);
        js_msg.velocity.resize(N);
        js_msg.effort.clear();

        for (unsigned int i = 0; i < N; i++) {
          TStatePerChannel &spc = encoder_states[i];

          js_msg.position[i] = spc.tickPos * joint_tick2rad[i];
          js_msg.velocity[i] = spc.instantaneousSpeed * joint_tick2rad[i];

          spc.instantaneousSpeed = 0; // Reset speed

          if (SPEED_FILTER_SAMPLES_LEN > 0) {
            if (!spc.speed_buffer_updated) {
              ROS_WARN("No speed data for this loop!");
              if (int(++spc.loops_without_update_speed_buffer) >=
                  SPEED_FILTER_IDLE_ITER_LOOPS_BEFORE_RESET) {
                libredaq::EncoderDecimatedSpeed e;
                e.header.stamp = ros::Time::now();
                e.header.frame_id = frame_id;
                e.avr_speed = .0;
                encoder_decimspeed_pubs[i].publish(e);
              }
            } else {
              spc.loops_without_update_speed_buffer = 0;

              if (int(spc.speeds_buffer.size()) >= SPEED_FILTER_SAMPLES_LEN) {
                const double avrg =
                    std::accumulate(spc.speeds_buffer.begin(),
                                    spc.speeds_buffer.end(), 0.0) /
                    spc.speeds_buffer.size();
                spc.speeds_buffer.clear();

                libredaq::EncoderDecimatedSpeed e;
                e.header.stamp = ros::Time::now();
                e.header.frame_id = frame_id;
                e.avr_speed = avrg * joint_tick2rad[i];
                encoder_decimspeed_pubs[i].publish(e);
              }
            }
          }
        }

        encoder_pub.publish(js_msg);

      } // end lock guard
    }   // end while ros::ok()

    return 0;

  } catch (std::exception &e) {
    ROS_ERROR("Exception: %s", e.what());
    return 1;
  }
}

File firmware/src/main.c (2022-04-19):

/*+-------------------------------------------------------------------------+
  |                             LibreDAQ                                    |
  |                                                                         |
  | Copyright (C) 2015  Jose Luis Blanco Claraco                            |
  | Distributed under GNU General Public License version 3                  |
  |   See <http://www.gnu.org/licenses/>                                    |
  +-------------------------------------------------------------------------+  */

/**
 * \mainpage User Application template doxygen documentation
 *
 *
 */
#include <asf.h>

#include <system/ldaq_rt_scheduler.h>
#include <comms/ldaq_comms.h>
#include <firmware_modes/ldaq_firmware_modes.h>

int main (void)
{
	// Init everything:
	// ---------------------------------------------------------
	wdt_disable(WDT);  // Make sure the WDT is disabled.
	sysclk_init();     // Initialize system clock
	board_init();      // Init peripherals
	ldaq_comms_init(); // This also sets up the USB stack
	rt_sched_init();   // LibreDAQ Real-time Scheduler system
	cpu_irq_enable();  // Enable interrupts

	// LED flashes to signal restart:
	// ---------------------------------------------------------
	pio_set_pin_high(LED1_GPIO);pio_set_pin_high(LED2_GPIO); delay_ms(150);
	pio_set_pin_low (LED1_GPIO);pio_set_pin_high(LED2_GPIO); delay_ms(150);
	pio_set_pin_high(LED1_GPIO);pio_set_pin_low (LED2_GPIO); delay_ms(150);
	pio_set_pin_low(LED1_GPIO); pio_set_pin_low (LED2_GPIO); delay_ms(150);
	pio_set_pin_high(LED1_GPIO);pio_set_pin_high(LED2_GPIO);

	// Main infinite loop:
	// ---------------------------------------------------------
	while (1)
	{
		ldaq_comms_dispatch_incoming_cmds();  // Fixed idle task: dispatch rx cmds
		ldaq_comms_task_outbounds_queue();    // Fixed idle task: out pkgs
		firm_mode_run_main_loop();            // The rest of tasks: depending on user-set firmware mode
	}

}

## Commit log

2015-03-03 Start of Device class
2015-03-11 Start ADC example
2015-03-12 First sort-of-working ADC example! :+1:
2015-03-12 ADC example: save to file
2015-03-15 Fix build in gcc
    [Device.cpp, libredaq_example_adc.cpp]
2015-06-06 Update of shared frames hdr; include processing of encoders
2015-06-06 More correct parsing of encoders
    [libredaq_example_adc.cpp]
2015-06-10 Rename directory; added encoders example
2015-06-11 Synch frames header
2015-06-21 PGA-ADC is working
2015-06-27 Add driver for Windows
2015-07-15 New example: adc+encs. Data output format as double
2018-06-01 Change slot boards
    Slot 0: ADC. AD7606 module
    Slot 1: DAC. MAX5500 module
    Slot 2: Encoders.
2018-06-01 Add ROS node for Encoders
2018-08-16 Add board schematics
    [LDAQ-BASE.brd, LDAQ-BASE.sch, LDAQ-MINI.brd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]
2018-08-16 Add schematic License
2019-10-31 fix reading at high speed
    [libredaq_node.cpp]
2019-12-02 Add 832M1 sensor board
    [MEAS-832M1.brd, MEAS-832M1.sch]
2019-12-02 add new encoders module with non-obsolete chip
    [LDAQ-MOD-ENC4.brd, LDAQ-MOD-ENC4.sch]
2021-01-18 update from local copy
    [LDAQ-BASE.brd, LDAQ-BASE.sch]
2021-01-18 base board: use bidirectional 3.3-5V driver
    [LDAQ-BASE.brd, LDAQ-BASE.sch]
2021-01-18 Base: Use JTAG 50mils connector
    [LDAQ-BASE.brd, LDAQ-BASE.sch]
2021-02-21 Update connectors in BASE
    [LDAQ-BASE.brd, LDAQ-BASE.sch]
2021-02-21 optimized board size
    [LDAQ-BASE.brd, LDAQ-BASE.sch]
2021-02-21 more missing components in circuithub
    [LDAQ-BASE.brd, LDAQ-BASE.sch]
2021-03-21 Revision with CPLD (TODO: rewire)
    [LDAQ-BASE.sch, LDAQ-MOD-ENC4.brd, LDAQ-MOD-ENC4.sch]
2021-05-26 update adc8 board
    [LDAQ-MOD-ADC8.brd, LDAQ-MOD-ADC8.sch]
2021-05-26 done with adc8 board
    [LDAQ-MOD-ADC8.brd, LDAQ-MOD-ADC8.sch]
2021-09-21 Start upgrade to another FPGA
    [LDAQ-MOD-ENC4.brd, LDAQ-MOD-ENC4.sch]
2021-09-30 New accelerometer board
    [MEAS-ADXL354.brd, MEAS-ADXL354.sch]
2021-09-30 update board
    [MEAS-ADXL354.brd, MEAS-ADXL354.csv]
2022-04-19 fix windows build; adc to slot 0
    [ldaq_mod_ad7606.h]

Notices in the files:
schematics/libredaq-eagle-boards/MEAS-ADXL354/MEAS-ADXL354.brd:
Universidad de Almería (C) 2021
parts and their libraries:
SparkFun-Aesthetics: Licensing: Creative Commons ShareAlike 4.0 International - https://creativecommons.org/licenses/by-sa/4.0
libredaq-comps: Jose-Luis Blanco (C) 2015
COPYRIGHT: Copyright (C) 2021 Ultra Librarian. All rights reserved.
